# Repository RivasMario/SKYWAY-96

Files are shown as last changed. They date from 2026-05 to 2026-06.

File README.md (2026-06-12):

# SKYWAY 96 — Hotswap Keyboard PCB

A 96% mechanical keyboard PCB built around the RP2040, with Kailh hotswap sockets and underglow RGB. Designed for JLCPCB assembly and Melody96-compatible cases.

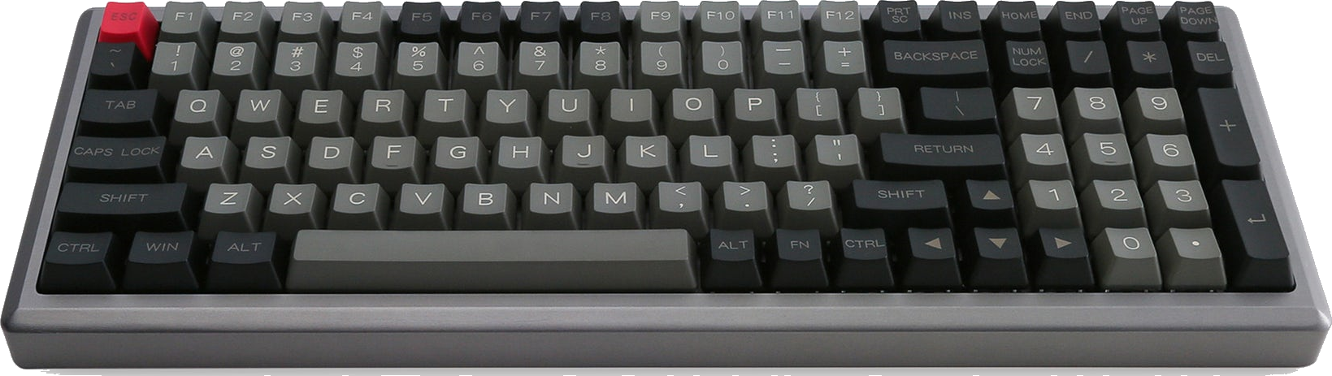
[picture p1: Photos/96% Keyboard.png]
Keyboard


## Contents

- [Specs](#specs)
- [Photos & Renders](#photos--renders)
- [Layout](#layout)
- [Repository Layout](#repository-layout)
- [Firmware: Setup & Flashing](#firmware-setup--flashing)
- [Troubleshooting](#troubleshooting)
- [Credits](#credits)

---

## Specs

| | |
|---|---|
| MCU | RP2040 (QFN-56) |
| Flash | W25Q128JVS (128 Mb, SOIC-8) |
| Layout | 96% — 99 keys |
| Switches | Kailh hotswap (MX compatible) |
| RGB | 18× WS2812B underglow |
| USB | USB-C (HRO TYPE-C-31-M-12) |
| Regulator | AMS1117-3.3 |
| ESD | PRTR5V0U2X |
| Firmware | QMK + VIA / Vial |
| Case | Melody96 / YMDK96 compatible (see [`Case/`](Case/)) |

---

## Photos & Renders

| Rendered Top | Rendered Back |
|---|---|
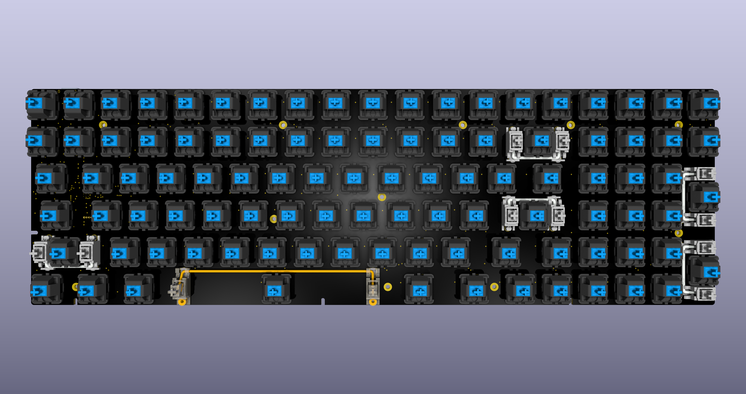
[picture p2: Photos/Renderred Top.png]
Rendered Top
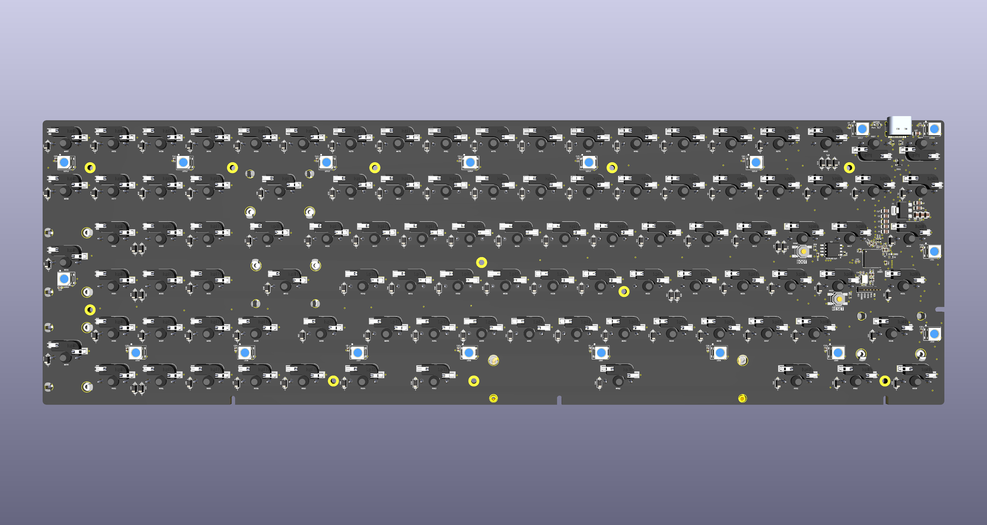
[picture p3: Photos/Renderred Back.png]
Rendered Back
|  |  |

| Board Top | Board Bottom |
|---|---|
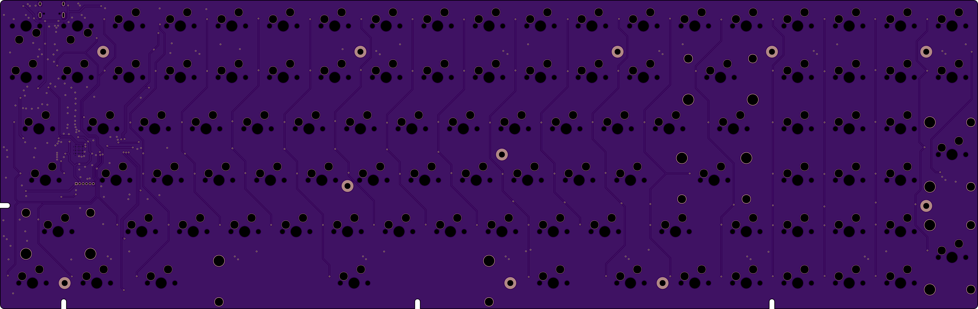
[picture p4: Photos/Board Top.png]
Board Top
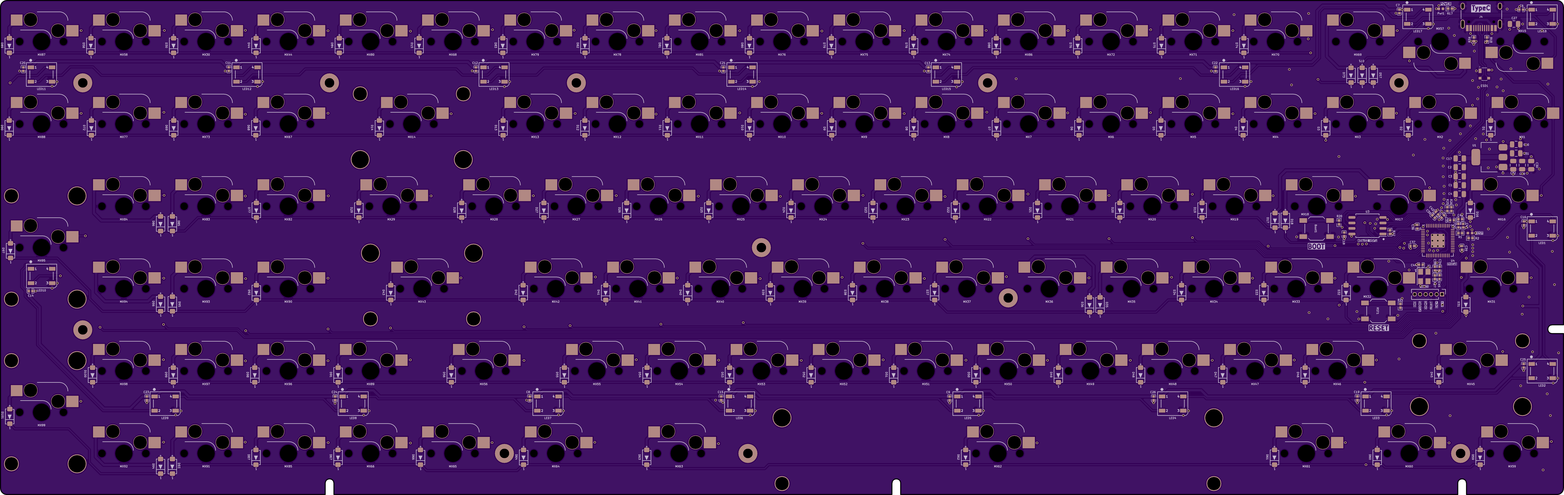
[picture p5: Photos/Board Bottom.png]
Board Bottom
|  |  |

All renders and 2D images (keycaps, stabilizers, layouts, alternate angles) live in [`Photos/`](Photos/).

### Switch Plate

Switch/stabilizer mounting plate (99 cutouts, 11× Ø4.0 screw holes, 361.95×114.30 mm).
DXF + details in [`Plate/`](Plate/).

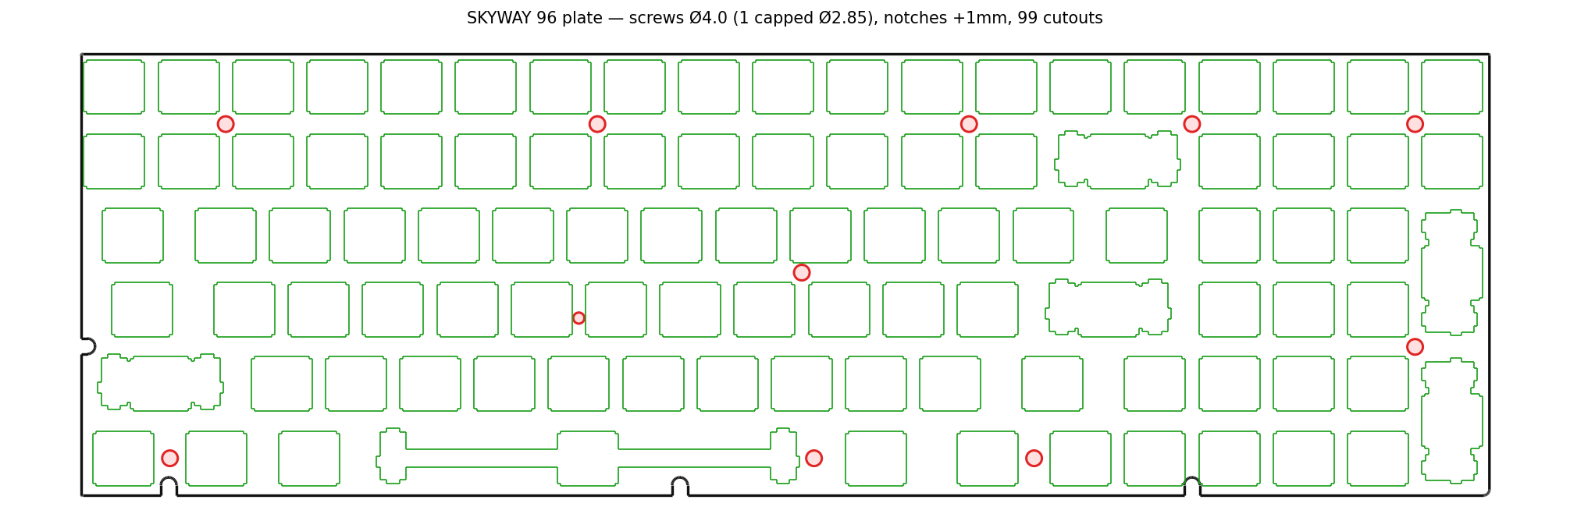
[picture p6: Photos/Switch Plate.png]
Switch plate


### 3D-Printable Cases

Two Melody96-compatible printed cases — pick either. Full part breakdowns in [`Case/`](Case/).

| Melody96 (HughMann) | RobotDoctor 96% |
|---|---|
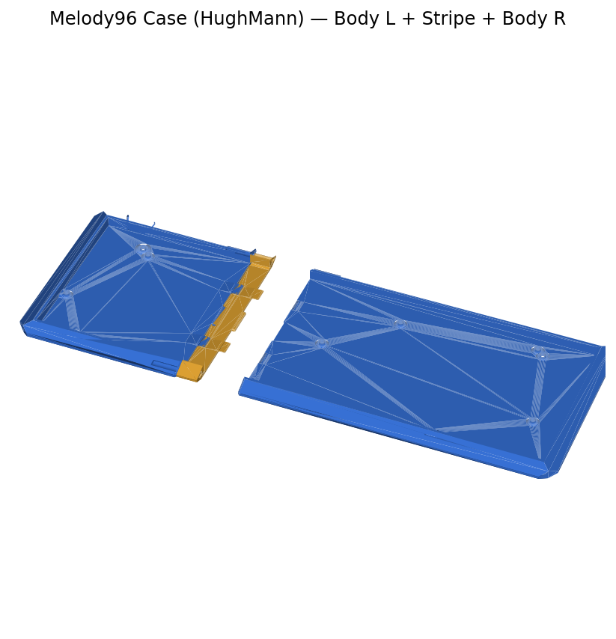
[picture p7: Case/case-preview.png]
Melody96 case
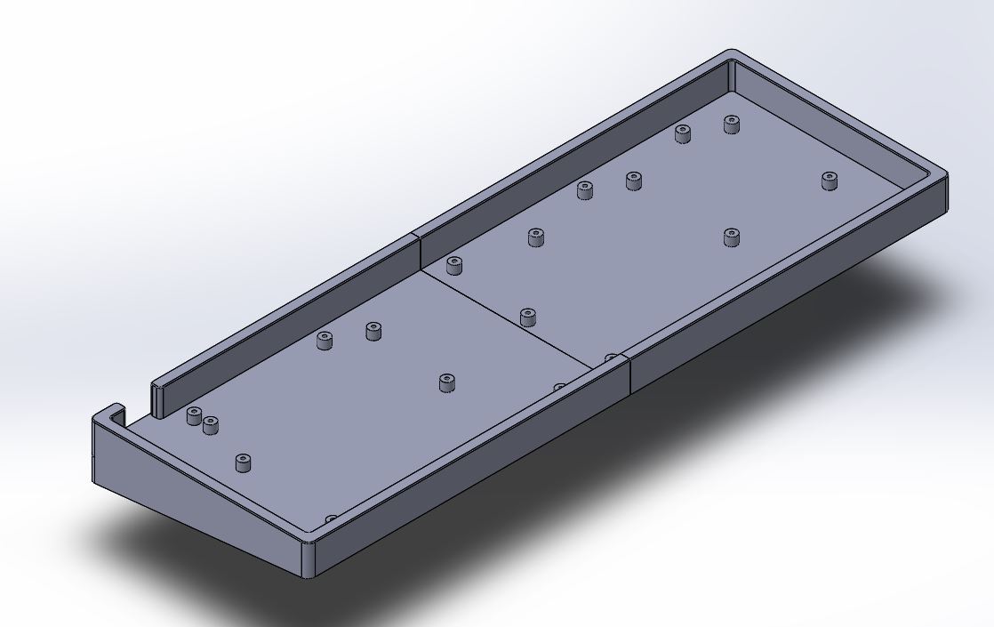
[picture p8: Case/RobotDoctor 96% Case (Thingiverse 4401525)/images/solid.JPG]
RobotDoctor case
|  |  |
| Multi-part: Body L/R + Stripe + Risers. [Details »](<Case/README.md>) · [Thingiverse #3883](https://www.thingiverse.com/thing:3883) | Tray-style, flat or angled. PCB-mount holes opened to Ø2.4 (M2). [Details »](<Case/RobotDoctor%2096%25%20Case%20%28Thingiverse%204401525%29/README.md>) · [Thingiverse #4401525](https://www.thingiverse.com/thing:4401525) |

---

## Layout

96% — 99 keys. Matrix is 6 rows × 19 columns (COL2ROW).

| 2D Layout | KLE |
|---|---|
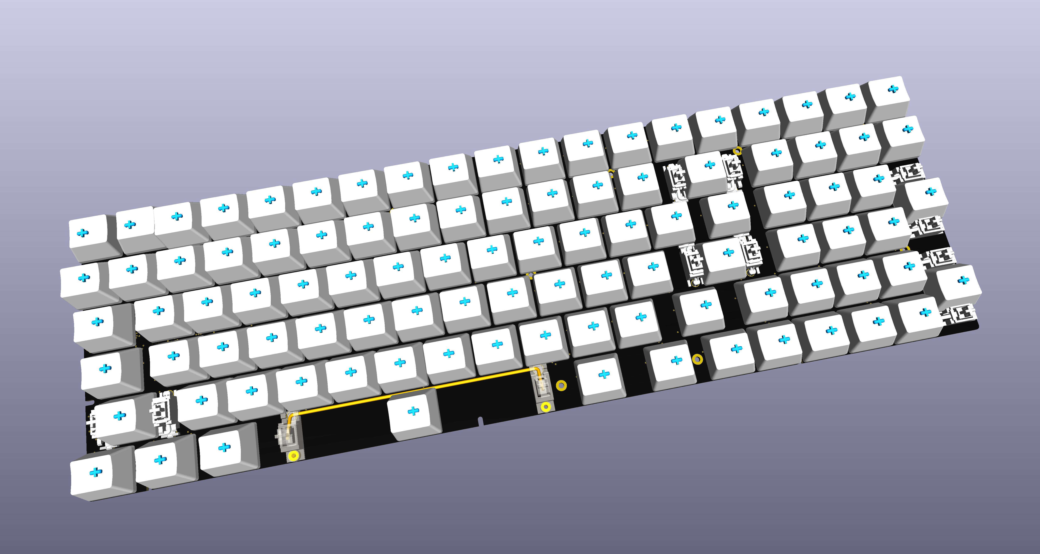
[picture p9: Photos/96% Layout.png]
96% Layout
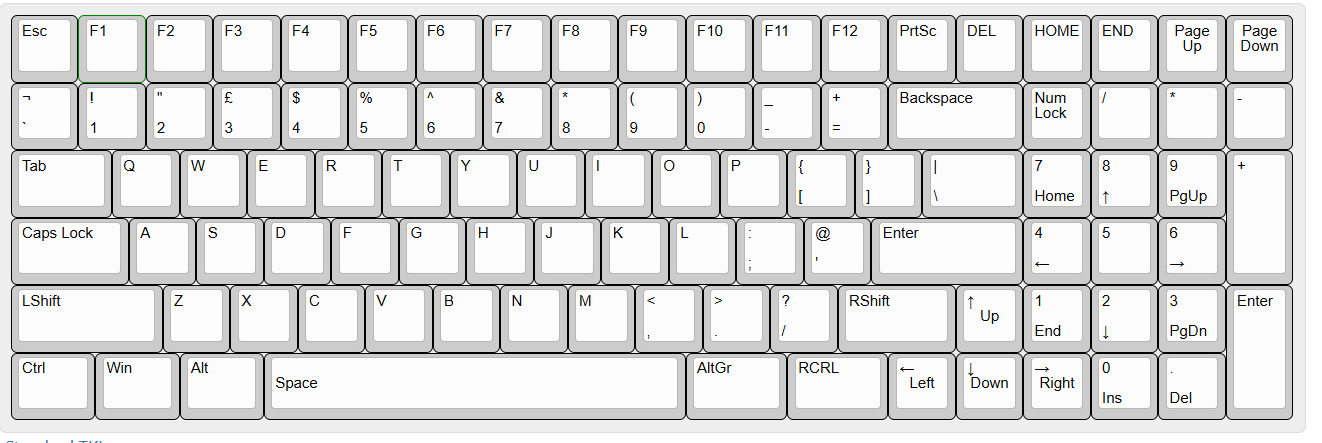
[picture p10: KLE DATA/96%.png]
Layout
|  |  |

Wiring, key labels, and VIA labelling diagrams are in [`KLE DATA/`](<KLE%20DATA/>).

---

## Repository Layout

| Folder | Contents |
|---|---|
| [`qmk_src/`](qmk_src/) | QMK firmware source + VIA keymap |
| [`Manufacturing & Assembly Files/`](<Manufacturing%20&%20Assembly%20Files/>) | BOM, CPL, Gerbers (for JLCPCB) |
| [`KiCAD Source Files/`](<KiCAD%20Source%20Files/>) | KiCad project + schematics |
| [`Schematic/`](Schematic/) | Schematic PDF |
| [`3D Step File/`](<3D%20Step%20File/>) | STEP / 3D model files |
| [`Photos/`](Photos/) | Renders and 2D images |
| [`KLE DATA/`](<KLE%20DATA/>) | Keyboard-Layout-Editor data + diagrams |
| [`VIA Json/`](<VIA%20Json/>) | VIA / Vial config + layout backups |
| [`Layout PDFs/`](<Layout%20PDFs/>) | Printable layout / keymap PDFs |
| [`Plate/`](Plate/) | Switch plate DXF (laser/waterjet) |
| [`Case/`](Case/) | 3D-printable cases (Melody96 + RobotDoctor) |

---

## Firmware: Setup & Flashing

### 1. Install the toolchain
You need the [QMK CLI](https://docs.qmk.fm/newbs_getting_started) and the `arm-none-eabi` toolchain. On Fedora:
```bash
sudo dnf install -y arm-none-eabi-gcc-cs-c++ arm-none-eabi-newlib arm-none-eabi-binutils
```

### 2. Link the source into QMK
```bash
ln -sf "$(pwd)/qmk_src" ~/qmk_firmware/keyboards/skyway96
```

### 3. Compile
```bash
qmk compile -kb skyway96 -km via
```
Produces `skyway96_via.uf2` in your `qmk_firmware` directory.

### 4. Flash
1. Enter bootloader: **hold BOOT → tap RESET → release BOOT**.
2. The board mounts as a USB drive named `RPI-RP2`.
3. Drag `skyway96_via.uf2` onto that drive, **or** run:
   ```bash
   qmk flash -kb skyway96 -km via
   ```

---

## Troubleshooting

### Linux USB detection (udev)
If VIA / Remap doesn't see the board on Linux, add a udev rule:
```bash
export USER_GID=`id -g`; sudo --preserve-env=USER_GID sh -c 'echo "KERNEL==\"hidraw*\", SUBSYSTEM==\"hidraw\", ATTRS{idVendor}==\"6969\", ATTRS{idProduct}==\"0096\", MODE=\"0660\", GROUP=\"$USER_GID\", TAG+=\"uaccess\", TAG+=\"udev-acl\"" > /etc/udev/rules.d/99-skyway96.rules && udevadm control --reload && udevadm trigger'
```

### Restore the "known good" layout
A verified layout backup (with RGB controls on Layer 1) lives at:
`VIA Json/skyway96_GOOD_BACKUP_2026-04-23.json`
Sideload it in VIA / Remap after flashing.

### GitHub push fails (password auth disabled)
Switch the remote to SSH:
```bash
git remote set-url origin git@github.com:RivasMario/SKYWAY-96.git
```
Make sure your SSH key (e.g. `~/.ssh/github`) is loaded in your SSH agent or set in `~/.ssh/config`.

---

## Credits

- **PCB** — Ahsan Mehmood Awan · `engrahsanmehmoodawan@gmail.com`
- **Case (Melody96)** — HughMann · [Thingiverse #3883](https://www.thingiverse.com/thing:3883)
- **Case (RobotDoctor 96%)** — RobotDoctor · [Thingiverse #4401525](https://www.thingiverse.com/thing:4401525) · CC-BY

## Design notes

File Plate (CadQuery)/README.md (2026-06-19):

# SKYWAY 96 — 3D-Printable Switch Plate (CadQuery)

A **3D-printable** version of the switch plate, generated from the same validated
geometry as the laser-cut [`../Plate/skyway96_plate.dxf`](../Plate/) (99 switch
cutouts incl. combo + stabilizer, 11 screw holes, 4 edge notches, PCB frame
361.95 × 113.30 mm). Pairs with the case in
[`../Case/SKYWAY Custom (CadQuery)`](../Case/SKYWAY%20Custom%20(CadQuery)).

## Why it isn't a flat 1.5 mm sheet

MX top-clips are made for a **1.5 mm** plate. A flat 1.5 mm × 360 mm FDM print
warps, flexes, and is fragile. So this is a **stepped** plate:

```
top  ──┐  1.5 mm   exact DXF profile (14 mm body + 1 mm clip wings)  → clips snap
body ──┘  1.5 mm   opened to ≥16 mm square                           → housing clears
total      3.0 mm  → stiff, low warp
```

The switch top (14 mm) seats in the top layer and the clip catches the step
shelf at z = 1.5 mm — exactly like a real 1.5 mm plate. The wider lower layer
just clears the switch's bottom housing and adds rigidity.

## Files

| File | What |
|---|---|
| `plate.py` | Builds the one-piece stepped plate → `output/skyway96_plate.stl` |
| `plate_split.py` | Left + Right halves for a ~220 mm bed → `output/skyway96_plate_{left,right}.stl` |
| `preflight.py` | Overhang / bed-fit / warp check |
| `tools/run_model.py` | Runs a script, validates watertight, renders a 6-view PNG |

Regenerate (uses the case folder's `.venv`):

```bash
PY="../Case/SKYWAY Custom (CadQuery)/.venv/Scripts/python.exe"
"$PY" plate.py            # one-piece
"$PY" plate_split.py      # L/R halves
"$PY" preflight.py
```

## Variants

| Print | Size (mm) | Bed |
|---|---|---|
| `skyway96_plate.stl` | 361 × 113 × 3 | 350 mm+ only |
| `skyway96_plate_left.stl` | 198 × 113 × 3 | any ≥ 220 |
| `skyway96_plate_right.stl` | 176 × 113 × 3 | any ≥ 220 |

### Split seam
At **x = 192 mm**, clear of the spacebar. A 96% layout has no full-height clear
column (stagger), so the seam **jogs** around the 3 cutouts it would cross —
every switch hole stays whole in one half, and the jog tongues key the halves
together in X and Y. Glue the seam faces; the PCB + screws lock the final stack.

## Screw holes (adaptive)

Each of the 11 holes is grown **as large as its neighbourhood allows** while
keeping a printable **1.0 mm** wall to the nearest cutout / hole / edge:

- 3 roomy holes (bottom row, near the edge) → **Ø5.0** (clears an M2 washer / a
  driver tip)
- 8 holes boxed in between switch cutouts → **~Ø2.4–2.5** (M2 shaft clearance)

The laser plate ran Ø4.0 everywhere on ~0.3 mm walls — fine for FR4, but those
walls won't print in FDM, so the crowded holes are deliberately smaller here.
Tune with `SCREW_WALL` / `SCREW_CAP_D` in `plate.py`.

## Print recipe

- Material: **PETG** (or PLA); 0.2 mm layers, 4 walls, 20 % infill
- **Print top-face DOWN** (flip in slicer) → the 14 mm clip openings print crisp
  on the bed and the step shelf prints fully supported. (Printed bottom-down also
  works; the ~1 mm step ledge is a trivial bridge.)
- **No supports.**
- **Brim** — 360 mm (one-piece) / ~190 mm (halves) flat parts are warp-prone.

## Assembly

1. Drop switches through the plate; clips snap at the 1.5 mm step.
2. Seat the switch pins into the PCB hotswap sockets (plate + PCB sandwich).
3. (split) glue the two halves at the jogged seam before populating across it.
4. Screw the PCB down into the case standoffs as normal.

## Source

Geometry from KiCad `MX1–MX99` switch centers via the laser plate DXF
([KB_PLATE_VALIDATOR](https://github.com/RivasMario/KB_PLATE_VALIDATOR)),
re-lofted to a stepped solid in CadQuery (OpenCASCADE).

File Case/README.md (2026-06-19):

# Case — SKYWAY 96

Case preview

Two 3D-printable case designs fit the SKYWAY 96 PCB. Both target the **Melody96 / YMDK96** 96% footprint the board is based on.

| Design | Folder | Construction | Tilt | Bed need |
|---|---|---|---|---|
| **Melody96 (HughMann)** | `Melody96 Case (HughMann)/` | 3-piece: L + Stripe + R (+ one-piece remix) | optional 5° riser | small (split) → large (1pc) |
| **96% (RobotDoctor)** | `96% Case (RobotDoctor)/` | 2-piece: L + R | built into model (angle vs flat) | small |
| **SKYWAY Custom (CadQuery)** | `SKYWAY Custom (CadQuery)/` | tray, 15× M2 posts; 1-piece **or** lap-split L/R; 6° feet | flat or 6° feet | 369 mm 1pc / 220 mm split |

The **SKYWAY Custom** tray is an original parametric design (CadQuery) fitted to
*this* PCB's exact outline + USB position — see its README to edit/regenerate.

See each folder's `README.md` for the full parts list.

---

## Design spec — what you need to make your own case

Both cases are built around the **same PCB**, so the hard constraints below are fixed. Everything else (wall style, seam, tilt) is a design choice — the two cases just make different choices.

### Fixed constraints (from the PCB / 96% standard)
| Spec | Value | Source |
|---|---|---|
| Layout footprint | Melody96 / YMDK96 96% | board lineage |
| Key pitch | 19.05 mm | MX standard |
| Switch cutout | 14.0 × 14.0 mm | MX plate |
| Plate thickness | 1.5 mm | MX clip seat |
| Mount holes present | M2 (1.75 mm) + M3 (3.0 mm) | `NPTH.drl` |
| PCB outline ref | `3D Step File/PCB 3D.step` | exact edge + holes |

### How the two cases solve it
| Aspect | Melody96 (HughMann) | 96% (RobotDoctor) |
|---|---|---|
| Pieces | 3 (L + Stripe + R) | 2 (L + R) |
| Seam | center stripe joins halves | direct center seam |
| Alignment | printed dowels | model-mated edge |
| Tilt | separate 5° riser parts | baked in: **angle** or **flat** body |
| Wall options | standard **or** 2 mm | single wall (per variant) |
| Assembled W × D × H | 387.6 × 140.3 × 21.7 mm | ≈376 × 128.8 × 31.5 (angle) / 18.0 (flat) |
| Half max footprint | 221.9 × 140.3 mm (Body R) | 188.0 × 128.8 mm |
| PCB hold | standoffs + dowels + feet | integrated bosses |
| Extras included | risers, feet, dowels, standoffs, remixes | none — body only |

### Compare / contrast — takeaways
- **Modularity:** Melody96 is a kit (swap stripe, risers, wall thickness, remixes). RobotDoctor is monolithic — fewer choices, fewer parts to align.
- **Tilt strategy:** Melody96 = add-on riser (mix and match). RobotDoctor = pick angle vs flat at print time (no extra parts, but no in-between).
- **Print effort:** RobotDoctor halves (max 188 mm) print on any bed with no stripe/dowel steps. Melody96 split also fits small beds but has more pieces; its one-piece remix needs a ~388 mm bed.
- **Assembly:** Melody96 needs dowels + standoffs + feet. RobotDoctor mates halves directly.
- **Hardware:** Melody96 ships printable hardware (feet/dowels/standoffs); RobotDoctor expects you to mount the PCB to integrated bosses (see its `Images/pcb_marked_1.jpg`).

### To design a fresh case
1. Pull exact outline + hole positions from `3D Step File/PCB 3D.step`.
2. Pull key positions from `skyway96.layout.json` (or `KLE DATA/`).
3. Use the fixed constraints table above for plate cutouts (19.05 pitch, 14×14, 1.5 mm).
4. Choose construction (tray / sandwich / split like these two), tilt, wall thickness.

Want a parametric OpenSCAD case generated from these? Pick tray vs sandwich and a tilt angle.

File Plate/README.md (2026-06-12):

# Switch Plate

Switch/stabilizer mounting plate for the SKYWAY 96 PCB.

Switch plate

| | |
|---|---|
| Size | 361.95 × 114.30 mm |
| Switch cutouts | 99 (Cherry MX, 14 mm) incl. combo cutouts (space, enter, backspace, numpad enter/plus) |
| Screw holes | 11 × **Ø4.0** (M2 + washer); 1 capped to Ø2.85 (PCB-constrained), aligned to PCB mounting holes |
| Edge notches | 4 (bottom + left + right), **grown +1 mm** for clearance |
| Format | `skyway96_plate.dxf` — layered (outline / switch / stab / screw) |

Cut from 1.5 mm FR4, brass, aluminium, or POM (laser / waterjet). The DXF is
SendCutSend-ready (no zero-length segments).

**Changes from PCB-exact:** screw holes opened Ø2.4→**Ø4.0** and notches grown
+1 mm for generous install wiggle; the bottom row left of the arrows is **2 wide
keys (1.5u each — RCtrl + Fn)** instead of three 1u, matching the PCB's two
switches there. Holes are sized **per-hole**: as big as Ø4.0 while keeping a
≥0.3 mm wall to the nearest switch cutout — one PCB-constrained hole is therefore
capped at Ø2.85. **Holes >3.8 mm need a washer** (M2 head is ~3.8 mm) — that's 10 of 11 here. Regenerate via `scripts/postprocess_plate.py --screw-dia ... --min-wall ...`.

## Source

Generated from the KLE layout + `KiCAD Source Files/*.kicad_pcb` by
[**KB_PLATE_VALIDATOR**](https://github.com/RivasMario/KB_PLATE_VALIDATOR),
which auto-registers the plate to the PCB and validates that every M2 screw
clears all switch/stab cutouts. Regenerate:

```bash
python scripts/build_plate.py \
  --kle skyway96_kle.json \
  --pcb "../skyway-96/KiCAD Source Files/rivasmario 96% Hotswap Rp2040.kicad_pcb" \
  --out output/skyway96_plate.dxf --pad 0 --snap-screws
```

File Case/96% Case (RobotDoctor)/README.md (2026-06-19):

# Case — 96% (RobotDoctor)

Second 3D-printable case option for the SKYWAY 96 PCB.

Design by **RobotDoctor** — [Thingiverse thing #4401525](https://www.thingiverse.com/thing:4401525). Files mirrored here for convenience; CC Attribution license (see `LICENSE.txt`).

## Print Layout

Prints in two halves (**left** + **right**), no center stripe. Choose **one** tilt variant:

```
[ left half ] [ right half ]
   angle  (5° typing tilt)
   flat   (0° low profile)
```

## Parts

### `Main Body/`
| File | Notes |
|---|---|
| `96plate_angle_left.STL` / `96plate_angle_right.STL` | Tilted variant — built-in typing angle |
| `96plate_flat_left.STL` / `96plate_flat_right.STL` | Flat variant — low profile |

> Print **either** the angle pair **or** the flat pair — not both.

## Dimensions (STL bounding box, mm)

| File | W × D × H |
|---|---|
| `96plate_angle_left` / `_right` | 188.0 × 31.5 × 128.8 |
| `96plate_flat_left` / `_right` | 188.0 × 18.0 × 128.8 |

Halves are modeled on their side (Z = board depth). Two halves seam at center → assembled width ≈ 376 mm. Fits the Melody96 / YMDK96 96% footprint shared by the SKYWAY 96 PCB.

## Print Tips

- **Material:** PLA or PETG.
- **Bed size:** each half ≈ 188 × 129 mm — fits most beds; no large-bed one-piece needed.
- **Orientation:** print as oriented (long axis up) for clean side walls, or lay flat if your slicer adds supports for the key cutouts.
- See `Images/pcb_marked_1.jpg` for PCB mounting reference.

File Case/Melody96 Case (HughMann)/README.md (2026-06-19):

# Case — Melody96 (HughMann, 3D Printable)

3D-printable case for the SKYWAY 96 PCB. The board shares the **Melody96 / YMDK96** footprint, so any Melody96-compatible case fits.

Design by **HughMann** — [Thingiverse thing #3883](https://www.thingiverse.com/thing:3883). Files mirrored here for convenience; original license terms apply.

## Print Layout

Prints in two halves (**Body L** + **Body R**) joined by a center **Stripe** accent piece. Add **Risers** for tilt and **Hardware** for assembly.

```
[ Body L ] [ Stripe ] [ Body R ]
              + Risers (tilt)
              + Feet / Dowels / Standoffs
```

## Parts

### `Main Body/`
| File | Notes |
|---|---|
| `Body L.stl` / `Body R.stl` | Left + right case halves (standard wall) |
| `Body L 2mm.stl` / `Body R 2mm.stl` | Thicker 2 mm wall variant — stiffer, more filament |
| `Stripe.stl` | Center accent strip that joins the two halves |
| `3 Part Stripe.stl` | Stripe split into 3 pieces — for smaller print beds |

> Print **either** the standard halves **or** the 2 mm halves — not both.

### `Risers/`
Add a 5° typing tilt.
| File | Notes |
|---|---|
| `5 Degree Riser Single Piece.stl` | One-piece riser (needs a large bed) |
| `5 Degree Riser L.stl` / `5 Degree Riser R.stl` | Split riser for smaller beds |

### `Hardware/`
| File | Notes |
|---|---|
| `Feet.stl` | Bottom feet |
| `Dowel.stl` | Alignment pins joining the case halves |
| `Extra standoff.stl` | Spare PCB mounting standoff |

### `Remixes/`
Community variants — alternate styling, same fit.
| File | Notes |
|---|---|
| `Granular Theory (Stoic Reluctance) Body L M2.stl` | Remix left half (M2 hardware) |
| `Granular Theory (Stoic Reluctance) Body R M2.stl` | Remix right half (M2 hardware) |
| `Granular Theory (Stoic Reluctance) Stripe M2.stl` | Remix center stripe |
| `Hope Lost (Sincerity or Rejection) One-Piece File.stl` | One-piece remix body |

## Dimensions (STL bounding box, mm)

| Part | W × D × H |
|---|---|
| Full assembled | 387.6 × 140.3 × 21.7 |
| Body L | 126.2 × 140.3 × 21.7 |
| Body R | 221.9 × 140.3 × 21.7 |
| Stripe | 20.5 × 138.3 × 21.7 |
| One-piece remix | 387.6 × 140.3 × 21.7 |
| 5° riser (1pc) | 342.5 × 15.0 × 10.2 |

## Print Tips

- **Material:** PLA or PETG.
- **Orientation:** print bodies flat (open side up) for clean key cutouts.
- **Bed size:** if a single-piece part won't fit, use the split equivalent (`3 Part Stripe`, split risers).
- **Mounting:** dowels align the halves; standoffs hold the PCB.

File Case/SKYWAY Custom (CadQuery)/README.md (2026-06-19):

# Case — SKYWAY Custom Tray (parametric, CadQuery)

Original tray case for the SKYWAY 96 PCB, built in **CadQuery** (Python/OpenCASCADE).
Every dimension is driven from *this repo's* gerbers + KiCad PCB — not guessed — so
it fits the real board. Fully parametric: edit the constants in `skyway_case.py`
and re-run.

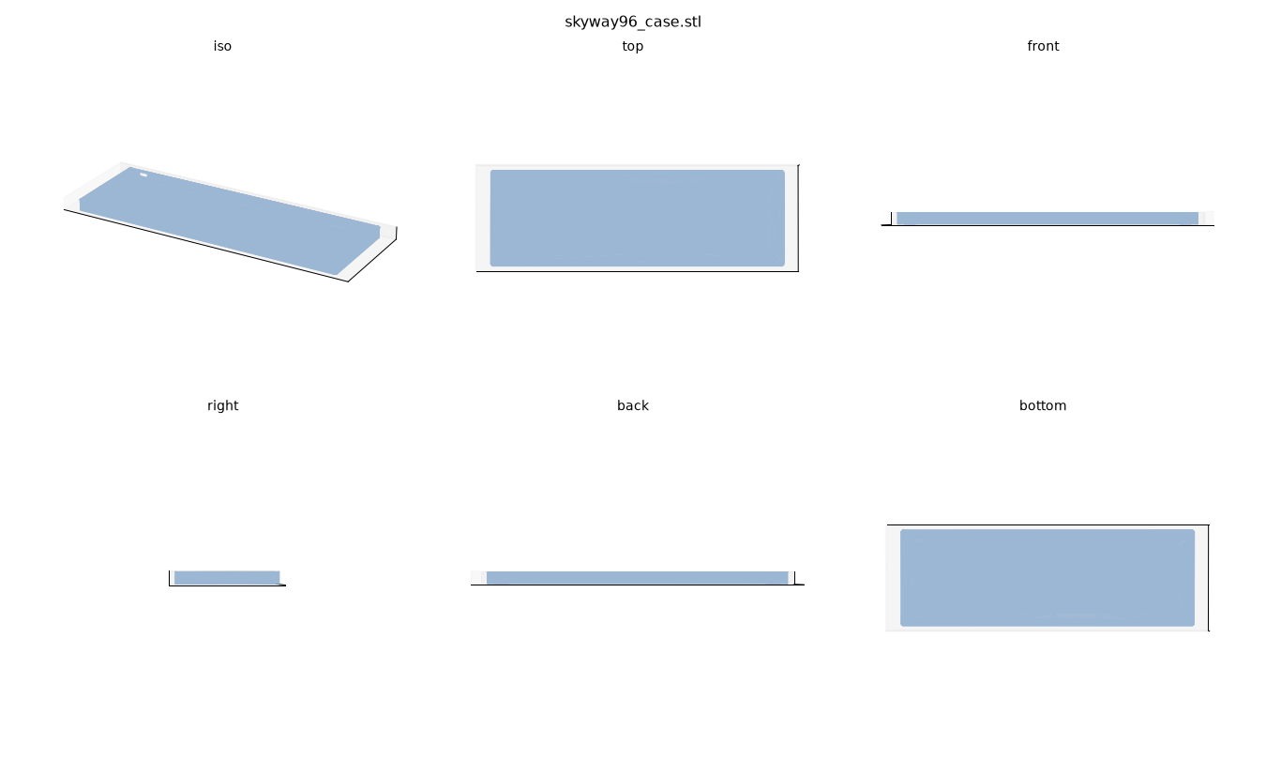
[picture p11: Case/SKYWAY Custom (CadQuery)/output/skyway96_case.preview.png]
preview


## What it is

A low-profile **screw-mounted tray**. The PCB drops in from the top and is held
three ways — anti-wobble by design:

1. **Continuous perimeter support ledge** (2.2 mm) under the PCB edge — all-around bearing.
2. **15 M2 standoff posts** — 11 at the PCB's internal mount holes + 4 at the
   edge screw-notches. The PCB screws **down** into them → clamped, not resting → no
   push-down bounce.
3. **Thin clamp lip** (0.8 mm) over the edge — backup hold-down between screws.

Ledge tops and post tops are coplanar at Z = 6.5 mm, so the PCB beds flat and
can't rock. All three features live in the 2.5 mm gap between the PCB edge and the
first switch housing, so nothing fouls switches or keycaps.

Fastening: **M2 heat-set brass inserts** (`screw_mode = "insert"`; 6.5 mm posts,
3.2 mm bore). Set `screw_mode = "selftap"` for screw-into-plastic (5 mm posts,
1.65 mm pilot) if you'd rather skip the inserts.

## Orientation (matches the physical board)

- **USB-C** exits the **far (+Y) wall, right end** — the diagonal corner
  (`USB_FAR_CORNER = True`).
- The **4 edge-notch posts** sit on the **opposite long edge** from the USB hole
  (`FLIP_X = True` mirrors the posts left↔right; the USB stays put).

The PCB only drops in one way (USB aligns to its cutout), so the assembly is
self-orienting — it can't go in backwards.

## Fit data (measured, not guessed)

| Source | Value |
|---|---|
| `Gerber File/...Edge_Cuts.gm1` | PCB outline **361.95 × 114.30 mm** |
| — | = exactly 19 × 6 keys @ 19.05 mm → the PCB *is* the switch grid, **no border** |
| `...kicad_pcb` (J4) | USB-C connector position |
| `...kicad_pcb` MountingHole + Edge.Cuts arcs | 11 M2 mount holes + 4 edge notches |
| 96% / MX standard | 19.05 pitch, 14 × 14 cutout, 2.5 mm edge-to-housing gap |

## Dimensions

| | mm |
|---|---|
| Outer (W × D × H) | **368.8 × 121.1 × 15.1** |
| Cavity (PCB pocket) | 362.8 × 115.1 |
| Wall / floor | 3.0 / 2.5 |
| PCB sits at Z | 6.5 (4.0 mm standoff above floor) |
| Material volume | ≈ 155 cm³ |

## Variants

| Script | Output | Bed |
|---|---|---|
| `model.py` | `skyway96_case.stl` | one-piece — needs **350 mm+** |
| `split.py` | `skyway96_left.stl` (~200 mm) + `skyway96_right.stl` (~175 mm) | **220 mm+** |
| `feet.py`  | `skyway96_foot.stl` — **print ×2** | any |

### Split — drop-in dovetails
Seam is offset to a **key-column gap** (centered-X +9.5 mm) so it misses every
standoff post. The joint is a row of **4 drop-in dovetails** on a raised **seam
rib**: each tenon flares in Y, so once seated the halves can't pull apart in X.
Tenons extrude vertically (constant in Z) → they **print support-free**, and you
**seat the right half straight down** onto the left. (A true *sliding* dovetail
can't work on a left/right split — the case bodies collide before the joint
engages.) The seam rib doubles as an **anti-sag gusset** and stays below the
hotswap sockets so it never touches the PCB.

The dovetails lock and align the **bottom**. The two long **walls just butt** —
**glue the seam faces** (superglue/epoxy) to lock the walls; the dovetails hold
the alignment while it sets. Glue is permanent and stronger than the plastic; for
a removable joint, model a bottom splice plate instead.

### Tilt — 6° dovetail-rail feet
One symmetric foot design (**print ×2**, one per channel). Each has a **male
dovetail rail** on its flat top that **slides along Y into a channel cut in the
case bottom** (added automatically when `FEET_DOVETAIL = True`). The dovetail
captures the foot — it can't drop off — and the wedge tilts the board **USB-edge
up** (front 3 mm → back 15.7 mm), the standard typing angle. Slide a foot into
each channel from the end; friction holds, add glue to make it permanent. Change
`FOOT["tilt_deg"]` in `skyway_case.py` for a different angle.

## Print recipe

- **Material:** PLA or PETG (PETG tougher at this span; print it in an enclosure).
- **Orientation:** body/halves open-side-up, floor flat on the bed. Feet on their
  **6° sloped face** (it's flat → fully supported).
- **Settings:** 0.2 mm layer, 3–4 walls, 15 % gyroid infill.
- **Supports:** none — every overhang is a short bridge (USB top, lip, dovetail
  flares ≤ ~13 mm). Verified by `preflight.py`.
- **Adhesion:** **brim** on the long flat parts — they're warp-prone.
- **First-layer compensation** (~0.15 mm) helps the dovetail fit (elephant's foot
  otherwise fattens the tenons).

## Bill of materials

- 15 × **M2 heat-set inserts** + 15 × M2 screws (PCB → posts)
- 2 × printed tilt feet (optional)
- **Glue / epoxy** for the split seam (if printing the split version)

## Assembly

1. Heat-set the **15 M2 inserts** into the posts.
2. *(split only)* seat the **right half down onto the left** so the dovetails
   drop in, then **glue the seam faces**.
3. Drop the **PCB** into the tray (rests on the ledge + post tops) and drive the
   **M2 screws** down through the PCB holes/notches into the posts.
4. *(optional)* slide a **tilt foot** into each bottom channel.

## Setup / regenerate

```bash
python -m venv .venv
.venv/Scripts/python.exe -m pip install cadquery trimesh numpy matplotlib
.venv/Scripts/python.exe tools/run_model.py model.py --preview   # build + 6-view PNG
.venv/Scripts/python.exe split.py        # split halves
.venv/Scripts/python.exe feet.py         # tilt foot
.venv/Scripts/python.exe preflight.py    # printability check
```

(`.venv` is gitignored — 761 MB, recreate with the commands above.)

## Parameters (in `skyway_case.py` unless noted)

| Param | Effect |
|---|---|
| `wall`, `floor`, `above_pcb` | thickness / stiffness / wall height above PCB |
| `lip_w`, `ledge_w` | clamp / support overhang (shrink if it clips switches) |
| `screw_mode` | `"insert"` (heat-set) or `"selftap"` |
| `FLIP_X` | mirror posts left↔right (USB fixed) |
| `USB_FAR_CORNER` | USB-C on the far wall, right end (diagonal corner) |
| `FEET_DOVETAIL` | cut the foot channels in the bottom |
| `FOOT["tilt_deg"]` | tilt angle of the feet |
| `BEZEL` / `STRIPE` | optional exterior flair (off by default) |
| seam / dovetail params (`split.py`) | seam X, dovetail count/size, clearance |

## Files

```
skyway_case.py   shared case builder (single source of truth)
model.py         one-piece body
split.py         L/R dovetail split
feet.py          6° tilt foot
preflight.py     printability / overhang check
tools/run_model.py   build runner + matplotlib 6-view preview
output/          generated STLs + preview PNGs
```

Built with the phased CAD workflow (base shell → features → fillets → flair),
each stage previewed and validated watertight before moving on.

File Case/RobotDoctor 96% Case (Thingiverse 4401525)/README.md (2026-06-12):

# RobotDoctor 96% Case (Thingiverse 4401525)

3D-printable case for a **96% mechanical keyboard** (Melody96 / YMDK96-class PCB),
an alternate to the [Melody96 (HughMann) case](../Melody96%20Case%20%28HughMann%29/).

Source design: **"Mechanical Keyboard Case for 96% Keyboard"** by
[RobotDoctor on Thingiverse](https://www.thingiverse.com/thing:4401525)
(thing **4401525**). Licensed **Creative Commons — Attribution (CC-BY)**.
See [`LICENSE.txt`](LICENSE.txt). This repo archives the original files,
adds build notes, and tracks local modifications.

## Render

Assembled case render

The case is a tray-style bottom: a perimeter wall with **standoffs** the PCB
screws down onto. Because a 96% board is long, the tray is **split into left +
right halves** so each fits a normal print bed; the seam sits mid-case.

## What's in here

| File | Half | Profile |
|---|---|---|
| [`plates/96plate_flat_left.STL`](plates/96plate_flat_left.STL) | left  | flat (0°) |
| [`plates/96plate_flat_right.STL`](plates/96plate_flat_right.STL) | right | flat (0°) |
| [`plates/96plate_angle_left.STL`](plates/96plate_angle_left.STL) | left  | angled (typing tilt) |
| [`plates/96plate_angle_right.STL`](plates/96plate_angle_right.STL)| right | angled (typing tilt) |

Pick **one profile** (flat *or* angle) and print **both halves** of it.

3D renders of the four modified plates (Ø2.4 bores):

| Flat | Angle |
|---|---|
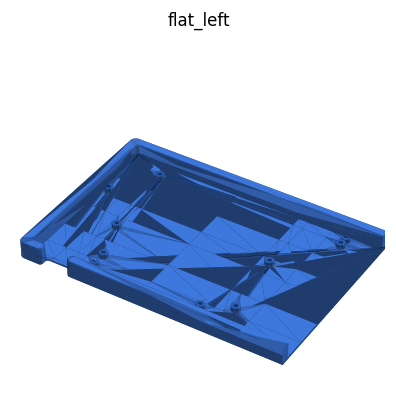
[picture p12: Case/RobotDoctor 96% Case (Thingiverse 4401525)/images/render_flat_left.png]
flat left
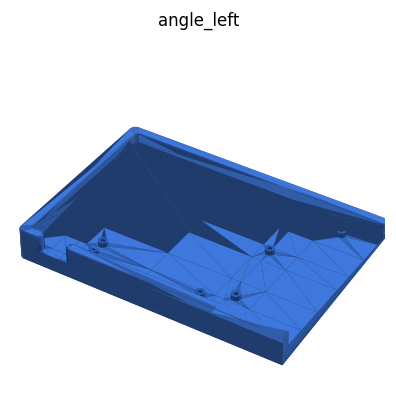
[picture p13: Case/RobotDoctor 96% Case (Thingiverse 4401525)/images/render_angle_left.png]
angle left
|  |  |
| `flat_left`  | `angle_left`  |
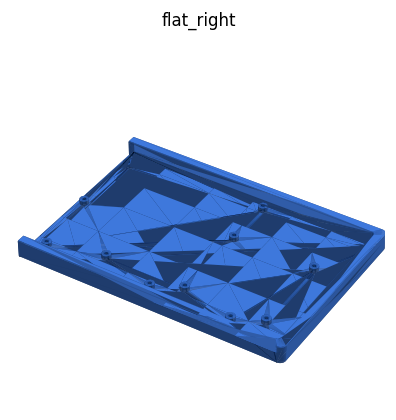
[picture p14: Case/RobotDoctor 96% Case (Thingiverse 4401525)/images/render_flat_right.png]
flat right
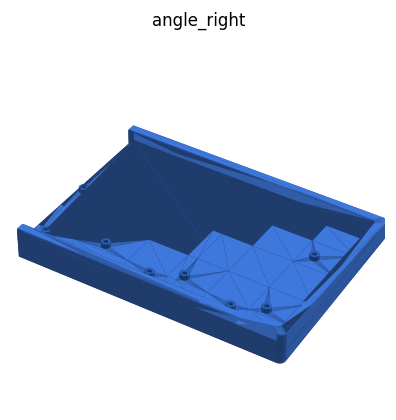
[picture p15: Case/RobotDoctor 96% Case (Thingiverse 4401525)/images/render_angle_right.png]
angle right
|  |  |
| `flat_right` | `angle_right` |

PCB used, screw holes marked in red (tape measure for scale):

PCB with mounting holes marked

## Print

1. Choose profile — **flat** (board sits flat) or **angle** (built-in typing tilt).
2. Slice `*_left` and `*_right` of that profile.
   - Material: PLA or PETG.
   - Layer height: 0.2 mm.
   - Walls: ≥ 3 perimeters (the standoffs take screw load).
   - Infill: ≥ 20% (bump standoffs/walls denser if your slicer supports modifiers).
   - Supports: only if your orientation needs them; the tray prints best
     **open-side up** (flat on the bed) — no supports for the flat profile.
3. Print both halves.

## Assemble

1. Dry-fit the two printed halves together at the center seam.
2. Drop the **PCB** into the tray, aligning its mounting holes over the standoffs
   (see the marked photo above — ~14 points).
3. Screw the PCB down into the standoffs (M2 screws).
4. Seat switches/stabs, add plate/keycaps, close it up.

## Screw-hole fix (applied)

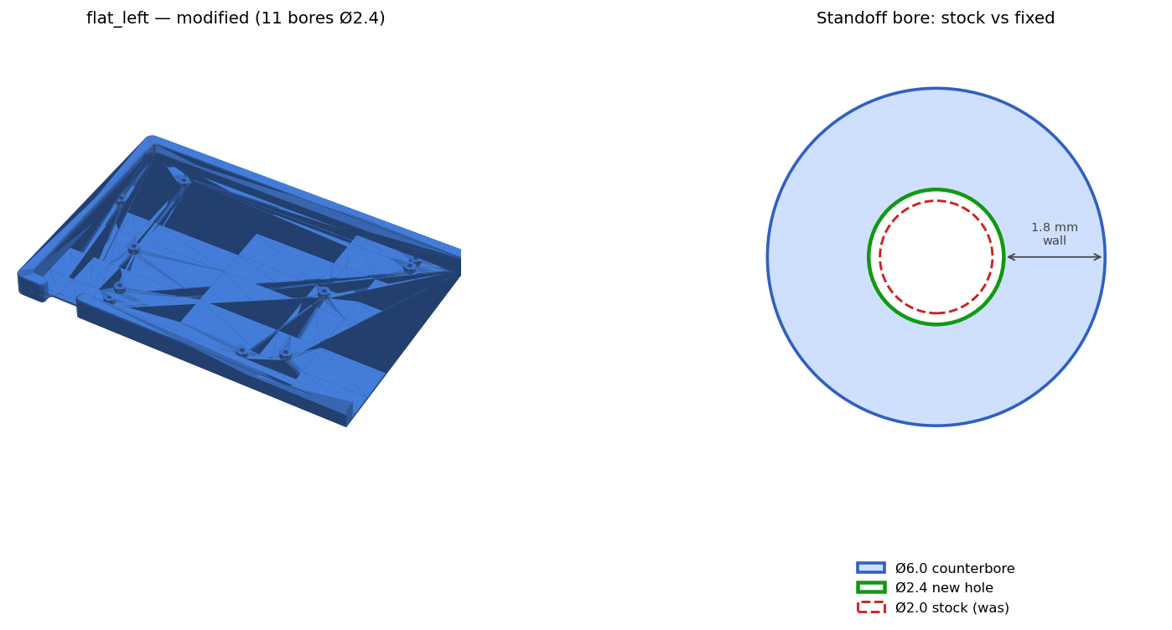
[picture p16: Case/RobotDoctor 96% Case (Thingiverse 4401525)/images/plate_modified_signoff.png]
Modified plate — 3D view + bore detail


*Left: modified `flat_left` (11 bores opened to Ø2.4). Right: standoff bore —
red dashed = Ø2.0 stock, green = Ø2.4 new, both inside the Ø6.0 counterbore;
~1.8 mm wall retained.*

The **stock** standoff holes are **Ø2.0 mm** — zero clearance for an M2 screw
(M2 major dia *is* 2.0 mm), so the screw won't pass and the holes had to be
drilled out by hand.

The STLs in [`plates/`](plates/) are **modified**: each of the 11 PCB-mount
bores per half is opened to **Ø2.4 mm** (M2 normal clearance) — screw passes
freely, head still seats in the Ø6 mm counterbore, ~1.8 mm wall retained. The
Ø6 counterbores and case corner/seam posts are untouched. Print these as-is —
no drilling needed.

- Unmodified Ø2.0 originals: [`original/plates/`](original/plates/).
- Re-cut: 4 plates × 11 bores, boolean difference (trimesh + manifold3d),
  result watertight. To change the diameter, copy back the originals and
  re-run with a different target.

## Credits

- Original design © [RobotDoctor](https://www.thingiverse.com/thing:4401525), CC-BY.
- Modifications and build notes: RivasMario.

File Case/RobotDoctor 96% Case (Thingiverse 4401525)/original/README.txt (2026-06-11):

Mechanical Keyboard Case for 96% Keyboard by RobotDoctor on Thingiverse: https://www.thingiverse.com/thing:4401525

Summary:
Mechanical Keyboard case made for a friend, sorry it took so long.

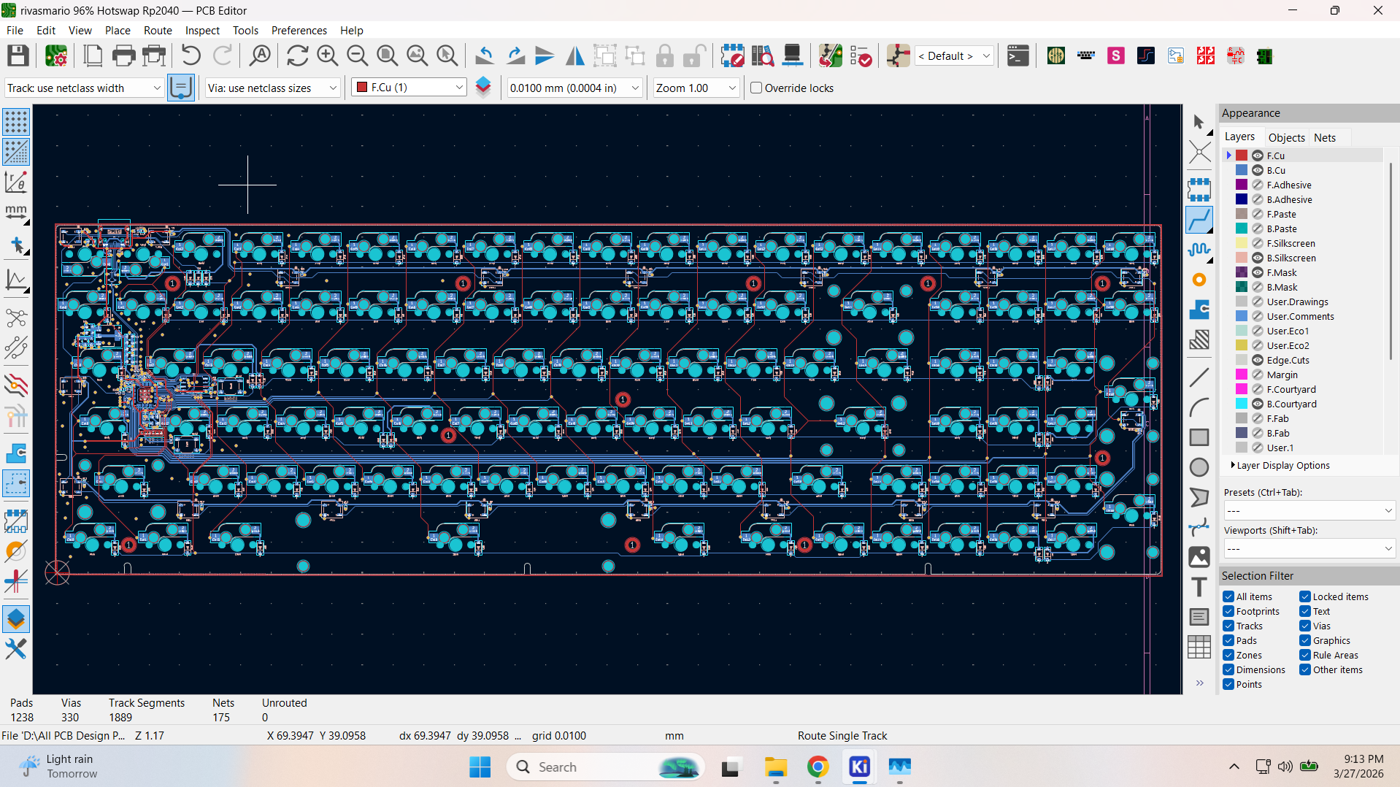
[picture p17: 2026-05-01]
Photos/PCB Layout.png

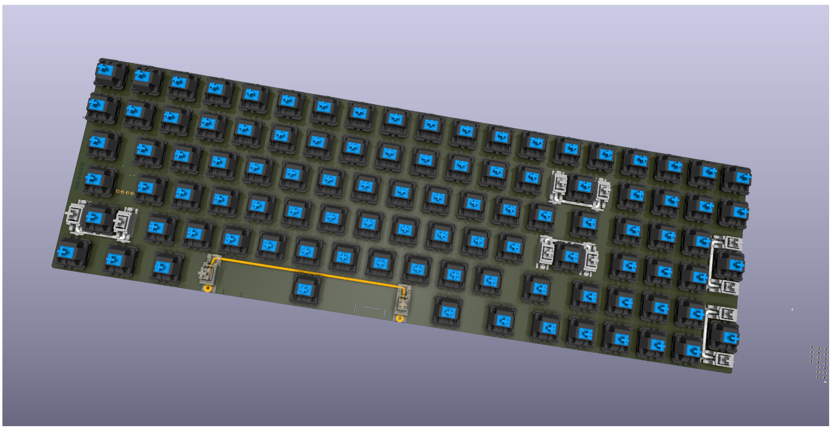
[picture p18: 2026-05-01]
Photos/3D.png

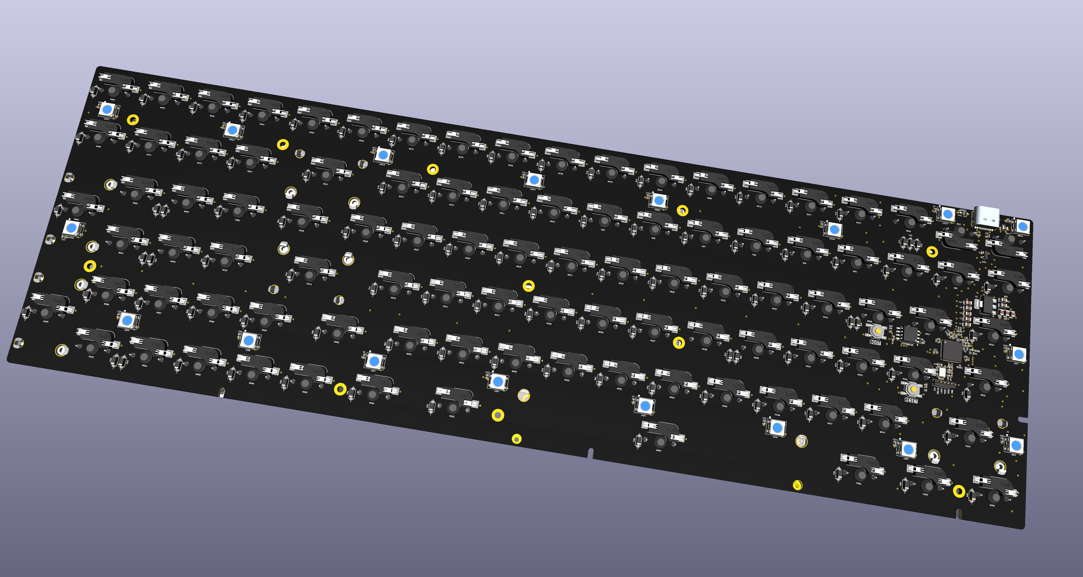
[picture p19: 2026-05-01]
Photos/back 3d.png

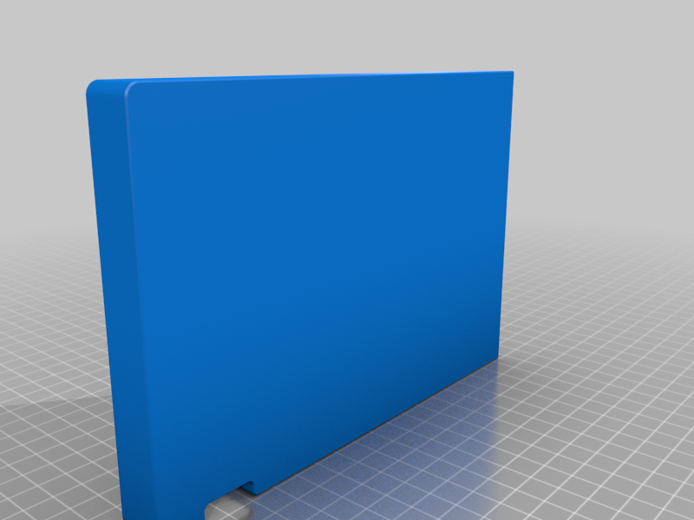
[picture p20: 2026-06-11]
Case/96% Case (RobotDoctor)/Images/96plate_flat_left.png

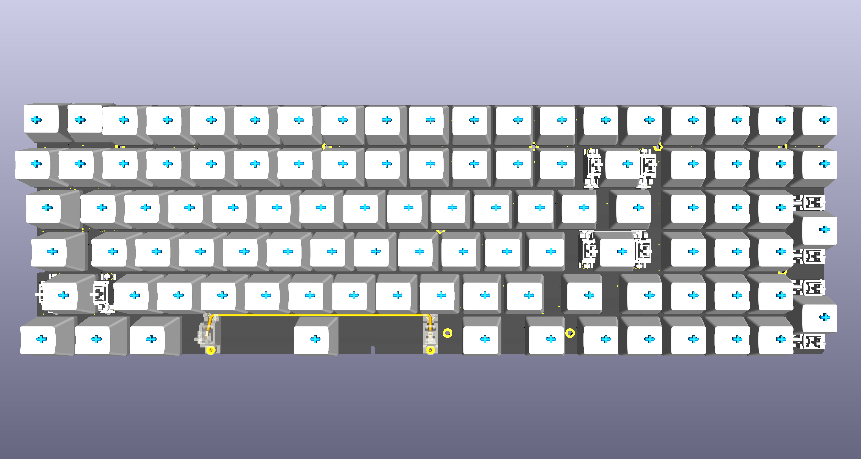
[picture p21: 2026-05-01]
Photos/Keycaps.png

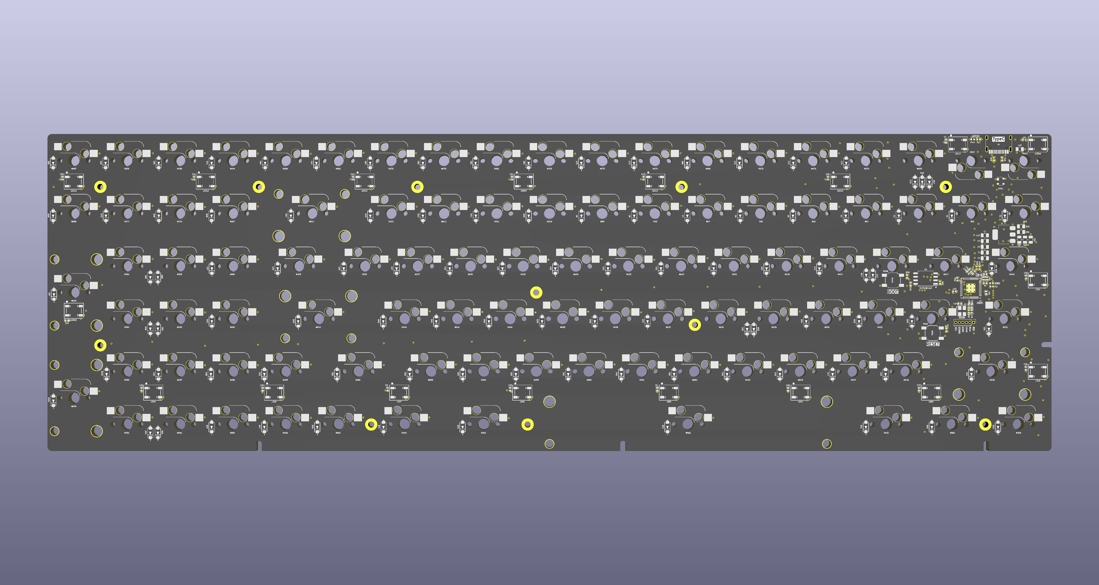
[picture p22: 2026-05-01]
Photos/Back 2D.png

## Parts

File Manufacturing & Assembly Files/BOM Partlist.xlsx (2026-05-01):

Reference | Value | Footprint | Qty | JLCPCB Part #
U1 | AMS1117-3.3 | Package_TO_SOT_SMD:SOT-223-3_TabPin2 | 1 | C6186
Test1 | LED | LED_SMD:LED_0402_1005Metric | 1 | C131223
Pwr1 | LED | LED_SMD:LED_0402_1005Metric | 1 | C131223
J4 | USB_C_Receptacle_USB2.0 | Ahsan Libs:USB_C_Receptacle_HRO_TYPE-C-31-M-12 | 1 | C165948
MX1,MX2,MX3,MX4,MX5,MX6,MX7,MX8,MX9,MX10,MX11,MX12,MX13,MX14,MX15,MX16,MX17,MX18,MX19,MX20,MX21,MX22,MX23,MX24,MX25,MX26,MX27,MX28,MX29,MX30,MX31,MX32,MX33,MX34,MX35,MX36,MX37,MX38,MX39,MX40,MX41,MX42,MX43,MX44,MX45,MX46,MX47,MX48,MX49,MX50,MX51,MX52,MX53,MX54,MX55,MX56,MX57,MX58,MX59,MX60,MX61,MX62,MX63,MX64,MX65,MX66,MX67,MX68,MX69,MX70,MX71,MX72,MX73,MX74,MX75,MX76,MX77,MX78,MX79,MX80,MX81,MX82,MX83,MX84,MX85,MX86,MX87,MX88,MX89,MX90,MX91,MX92,MX93,MX94,MX95,MX96,MX97,MX98,MX99 | MX-NoLED | Ahsan Libs:SW_Hotswap_Kailh_1.00u | 99 | C41430893
U3 | W25Q128JVS | Ahsan Libs:SOIC-8_5.23x5.23mm_P1.27mm | 1 | C97521
U4 | RP2040 | Ahsan Libs:RP2040-QFN-56 | 1 | C2040
ESD1 | PRTR5V0U2X | Ahsan Libs:PRTR5V0U2X | 1 | C2827688
LED1,LED2,LED3,LED4,LED5,LED6,LED7,LED8,LED9,LED10,LED11,LED12,LED13,LED14,LED15,LED16,LED17,LED18 | WS2812B | Ahsan Libs:LED_WS2812B_PLCC4_5.0x5.0mm_P3.2mm | 18 | C2761795
RST1 | SW_SPST | Ahsan Libs:K2-1187SQ-A4SW-06 | 1 | C92584
Boot1 | SW_SPST | Ahsan Libs:K2-1187SQ-A4SW-06 | 1 | C92584
C44,C45 | 22pf | Ahsan Libs:JLCPCB_C0402 | 2 | C1555
C33,C43 | 1uf | Ahsan Libs:JLCPCB_C0402 | 2 | C1518208
C5,C6,C7,C8,C9,C11,C12,C13,C14,C15,C16,C18,C19,C20,C21,C22,C23,C24,C25,C26,C34,C35,C36,C37,C38,C39,C40,C41,C42 | 100nf | Ahsan Libs:JLCPCB_C0402 | 29 | C77020
R25,R26 | 22 | Ahsan Libs:JLCPCB_R0402 | 2 | C25092
R21,R22 | 10k | Ahsan Libs:JLCPCB_R0402 | 2 | C25744
R20,R27 | 1k | Ahsan Libs:JLCPCB_R0402 | 2 | C11702
R18,R19 | 5.1K | Ahsan Libs:JLCPCB_R0402 | 2 | C25905
R1,R2,R17 | 470 | Ahsan Libs:JLCPCB_R0402 | 3 | C25117
D1,D2,D3,D4,D5,D6,D7,D8,D9,D10,D11,D12,D13,D14,D15,D16,D17,D18,D19,D20,D21,D22,D23,D24,D25,D26,D27,D28,D29,D30,D31,D32,D33,D34,D35,D36,D37,D38,D39,D40,D41,D42,D43,D44,D45,D46,D47,D48,D49,D50,D51,D52,D53,D54,D55,D56,D57,D58,D59,D60,D61,D62,D63,D64,D66,D67,D68,D69,D71,D72,D73,D74,D75,D76,D77,D78,D79,D80,D81,D82,D83,D84,D85,D86,D87,D88,D89,D90,D91,D92,D93,D94,D95,D96,D97,D98,D99,D100,D101 | 1N4148W | Ahsan Libs:D_SOD-123 | 99 | C81598
Y1 | 12MHz | Ahsan Libs:Crystal_SMD_3225-4Pin_3.2x2.5mm | 1 | C9002
C2,C4,C30,C32 | 100nf | Ahsan Libs:C_0805_2012Metric | 4 | C126469
C1,C3,C10,C17,C27,C29,C31 | 10uf | Ahsan Libs:C_0805_2012Metric | 7 | C440198

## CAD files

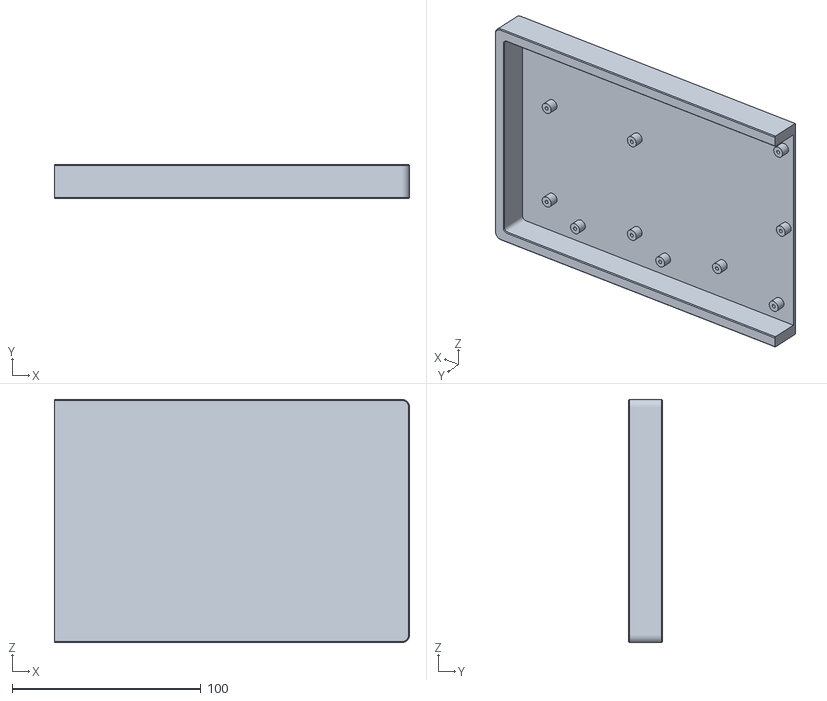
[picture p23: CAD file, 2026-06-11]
Case/96% Case (RobotDoctor)/Main Body/96plate_flat_right.STL
188.0 x 18.0 x 128.8

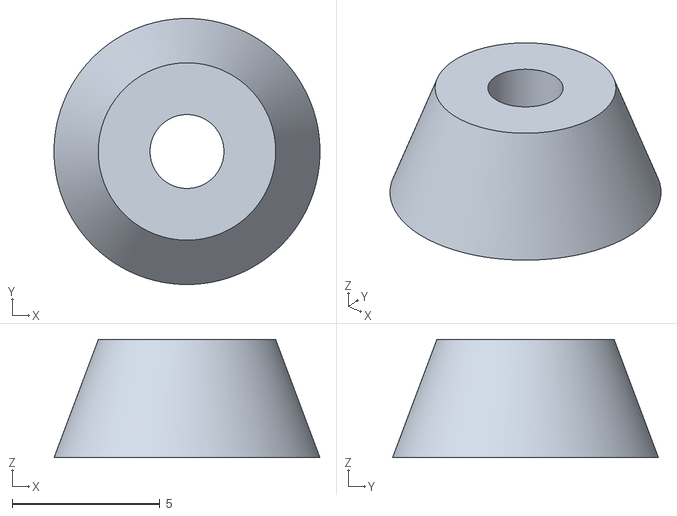
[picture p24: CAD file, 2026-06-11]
Case/Melody96 Case (HughMann)/Hardware/Extra standoff.stl
9.00 x 9.00 x 4.00

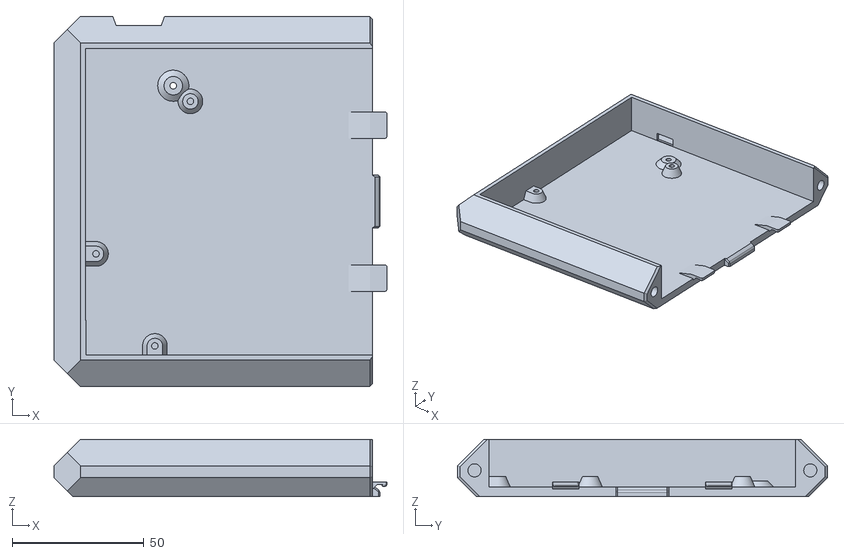
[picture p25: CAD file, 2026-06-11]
Case/Melody96 Case (HughMann)/Main Body/Body L 2mm.stl
126.2 x 140.3 x 21.7

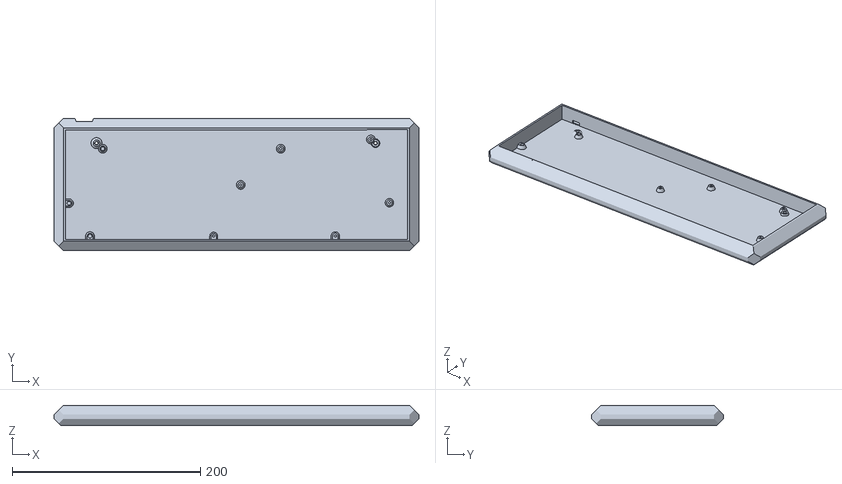
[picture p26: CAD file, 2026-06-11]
Case/Melody96 Case (HughMann)/Remixes/Hope Lost (Sincerity or Rejection) One-Piece File.stl
387.6 x 140.3 x 21.7

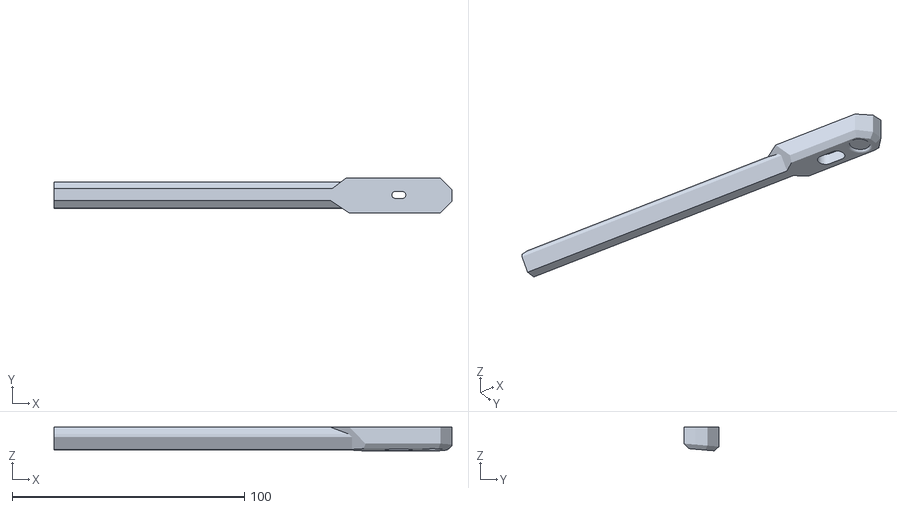
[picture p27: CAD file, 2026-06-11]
Case/Melody96 Case (HughMann)/Risers/5 Degree Riser L.stl
171.2 x 15.0 x 10.2

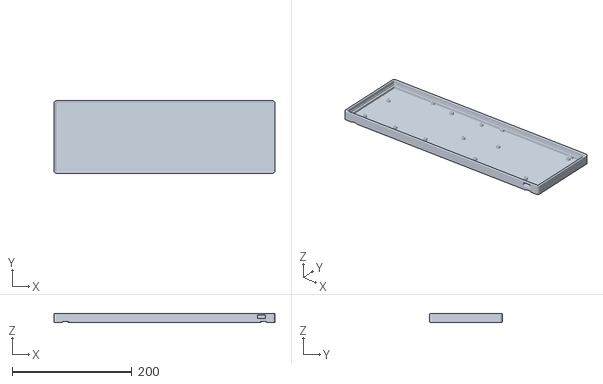
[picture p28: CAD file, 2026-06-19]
Case/SKYWAY Custom (CadQuery)/output/skyway96_case.stl
368.8 x 121.1 x 15.1

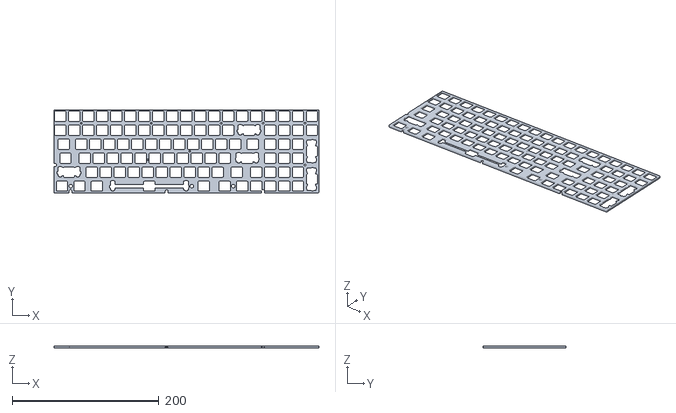
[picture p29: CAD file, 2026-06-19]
Plate (CadQuery)/output/skyway96_plate.stl
361.0 x 113.3 x 3.00

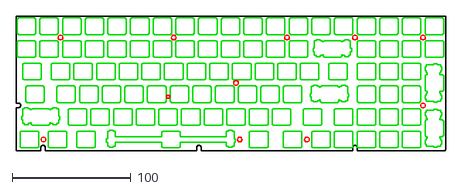
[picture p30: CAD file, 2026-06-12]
Plate/skyway96_plate.dxf
360.9 x 113.3

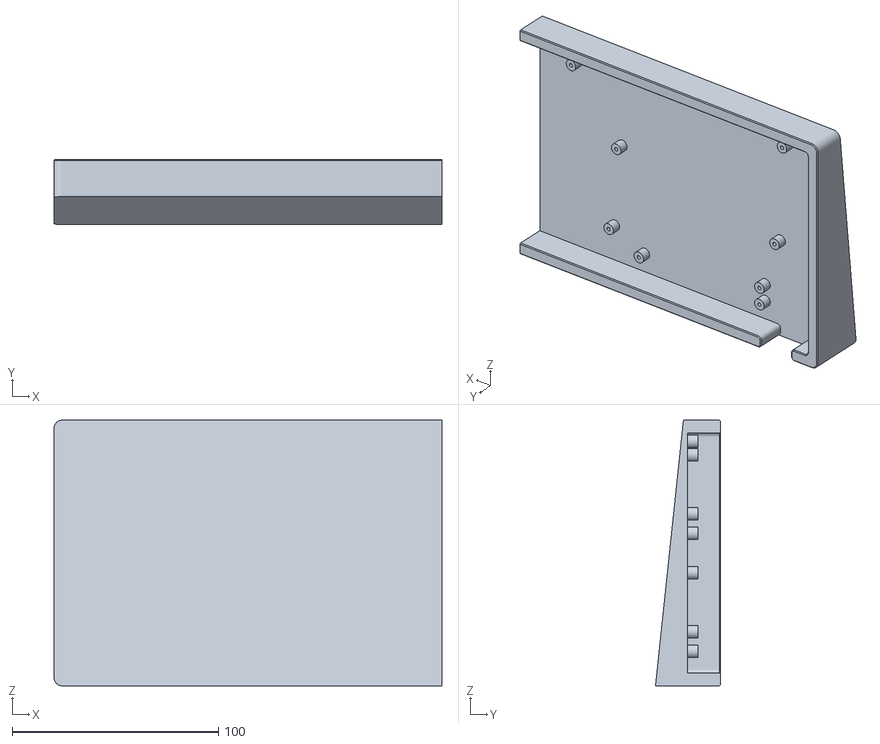
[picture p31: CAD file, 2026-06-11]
Case/96% Case (RobotDoctor)/Main Body/96plate_angle_left.STL
188.0 x 31.5 x 128.8

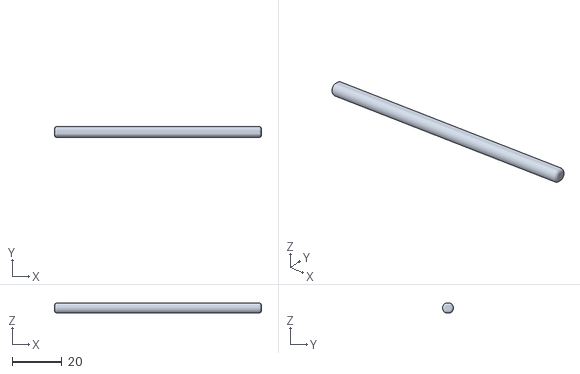
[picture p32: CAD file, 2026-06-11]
Case/Melody96 Case (HughMann)/Hardware/Dowel.stl
83.0 x 4.40 x 4.00

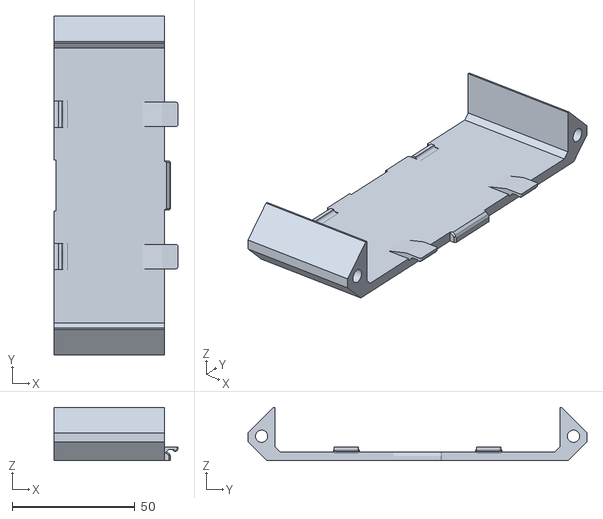
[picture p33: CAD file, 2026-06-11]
Case/Melody96 Case (HughMann)/Main Body/3 Part Stripe.stl
50.5 x 138.3 x 21.7

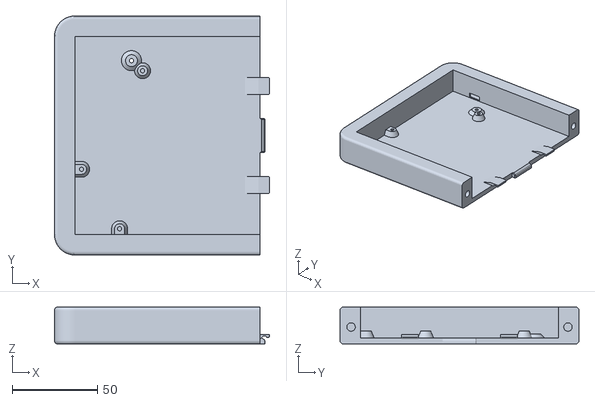
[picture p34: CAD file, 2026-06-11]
Case/Melody96 Case (HughMann)/Remixes/Granular Theory (Stoic Reluctance) Body L M2.stl
126.2 x 140.2 x 21.7

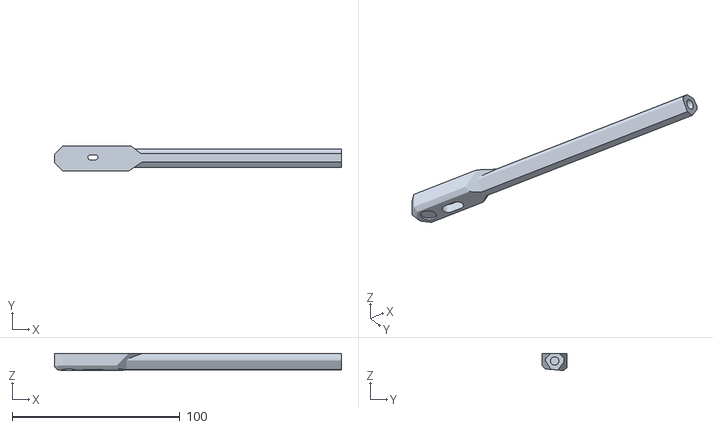
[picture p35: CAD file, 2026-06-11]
Case/Melody96 Case (HughMann)/Risers/5 Degree Riser R.stl
171.2 x 15.0 x 10.2

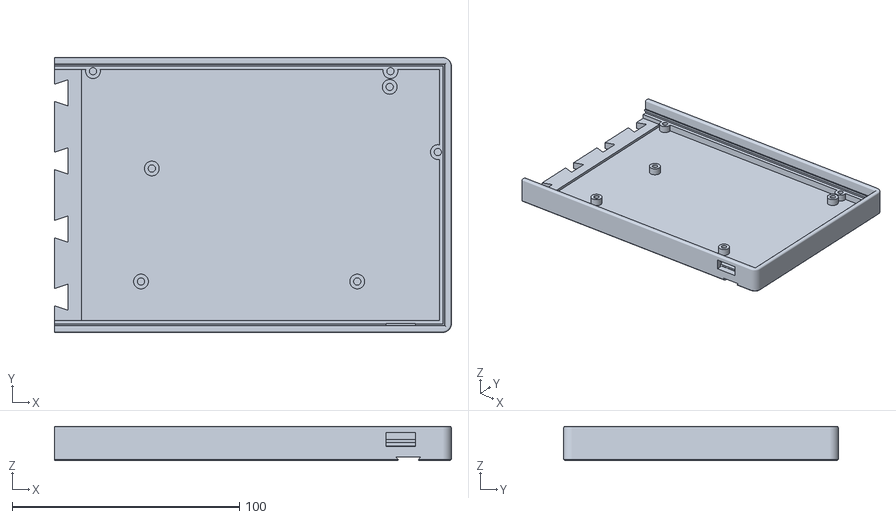
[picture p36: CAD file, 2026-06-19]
Case/SKYWAY Custom (CadQuery)/output/skyway96_right.stl
174.9 x 121.1 x 15.1

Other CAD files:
Plate (CadQuery)/output/skyway96_plate_right.stl
Case/96% Case (RobotDoctor)/Main Body/96plate_angle_right.STL
Case/Melody96 Case (HughMann)/Hardware/Feet.stl
Case/Melody96 Case (HughMann)/Main Body/Body R 2mm.stl
Case/96% Case (RobotDoctor)/Main Body/96plate_flat_left.STL
Case/Melody96 Case (HughMann)/Main Body/Body L.stl
Case/Melody96 Case (HughMann)/Main Body/Body R.stl
Case/Melody96 Case (HughMann)/Main Body/Stripe.stl
Case/Melody96 Case (HughMann)/Remixes/Granular Theory (Stoic Reluctance) Body R M2.stl
Case/Melody96 Case (HughMann)/Remixes/Granular Theory (Stoic Reluctance) Stripe M2.stl
Case/Melody96 Case (HughMann)/Risers/5 Degree Riser Single Piece.stl
Case/RobotDoctor 96% Case (Thingiverse 4401525)/plates/96plate_angle_left.STL
Case/RobotDoctor 96% Case (Thingiverse 4401525)/plates/96plate_angle_right.STL
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

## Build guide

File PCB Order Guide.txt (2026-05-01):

PCB Order Guide:

PCBWAY:
https://www.pcbway.com/helpcenter/Findproducts/How_do_I_place_an_order_.html
https://www.youtube.com/watch?v=HH-DKSiopYk

JLCPCB:
https://support.jlcpcb.com/article/21-how-do-i-place-an-order
https://oshwlab.com/CatherineAlson/How-to-Place-PCB-SMT-Order-on-JLCPCB

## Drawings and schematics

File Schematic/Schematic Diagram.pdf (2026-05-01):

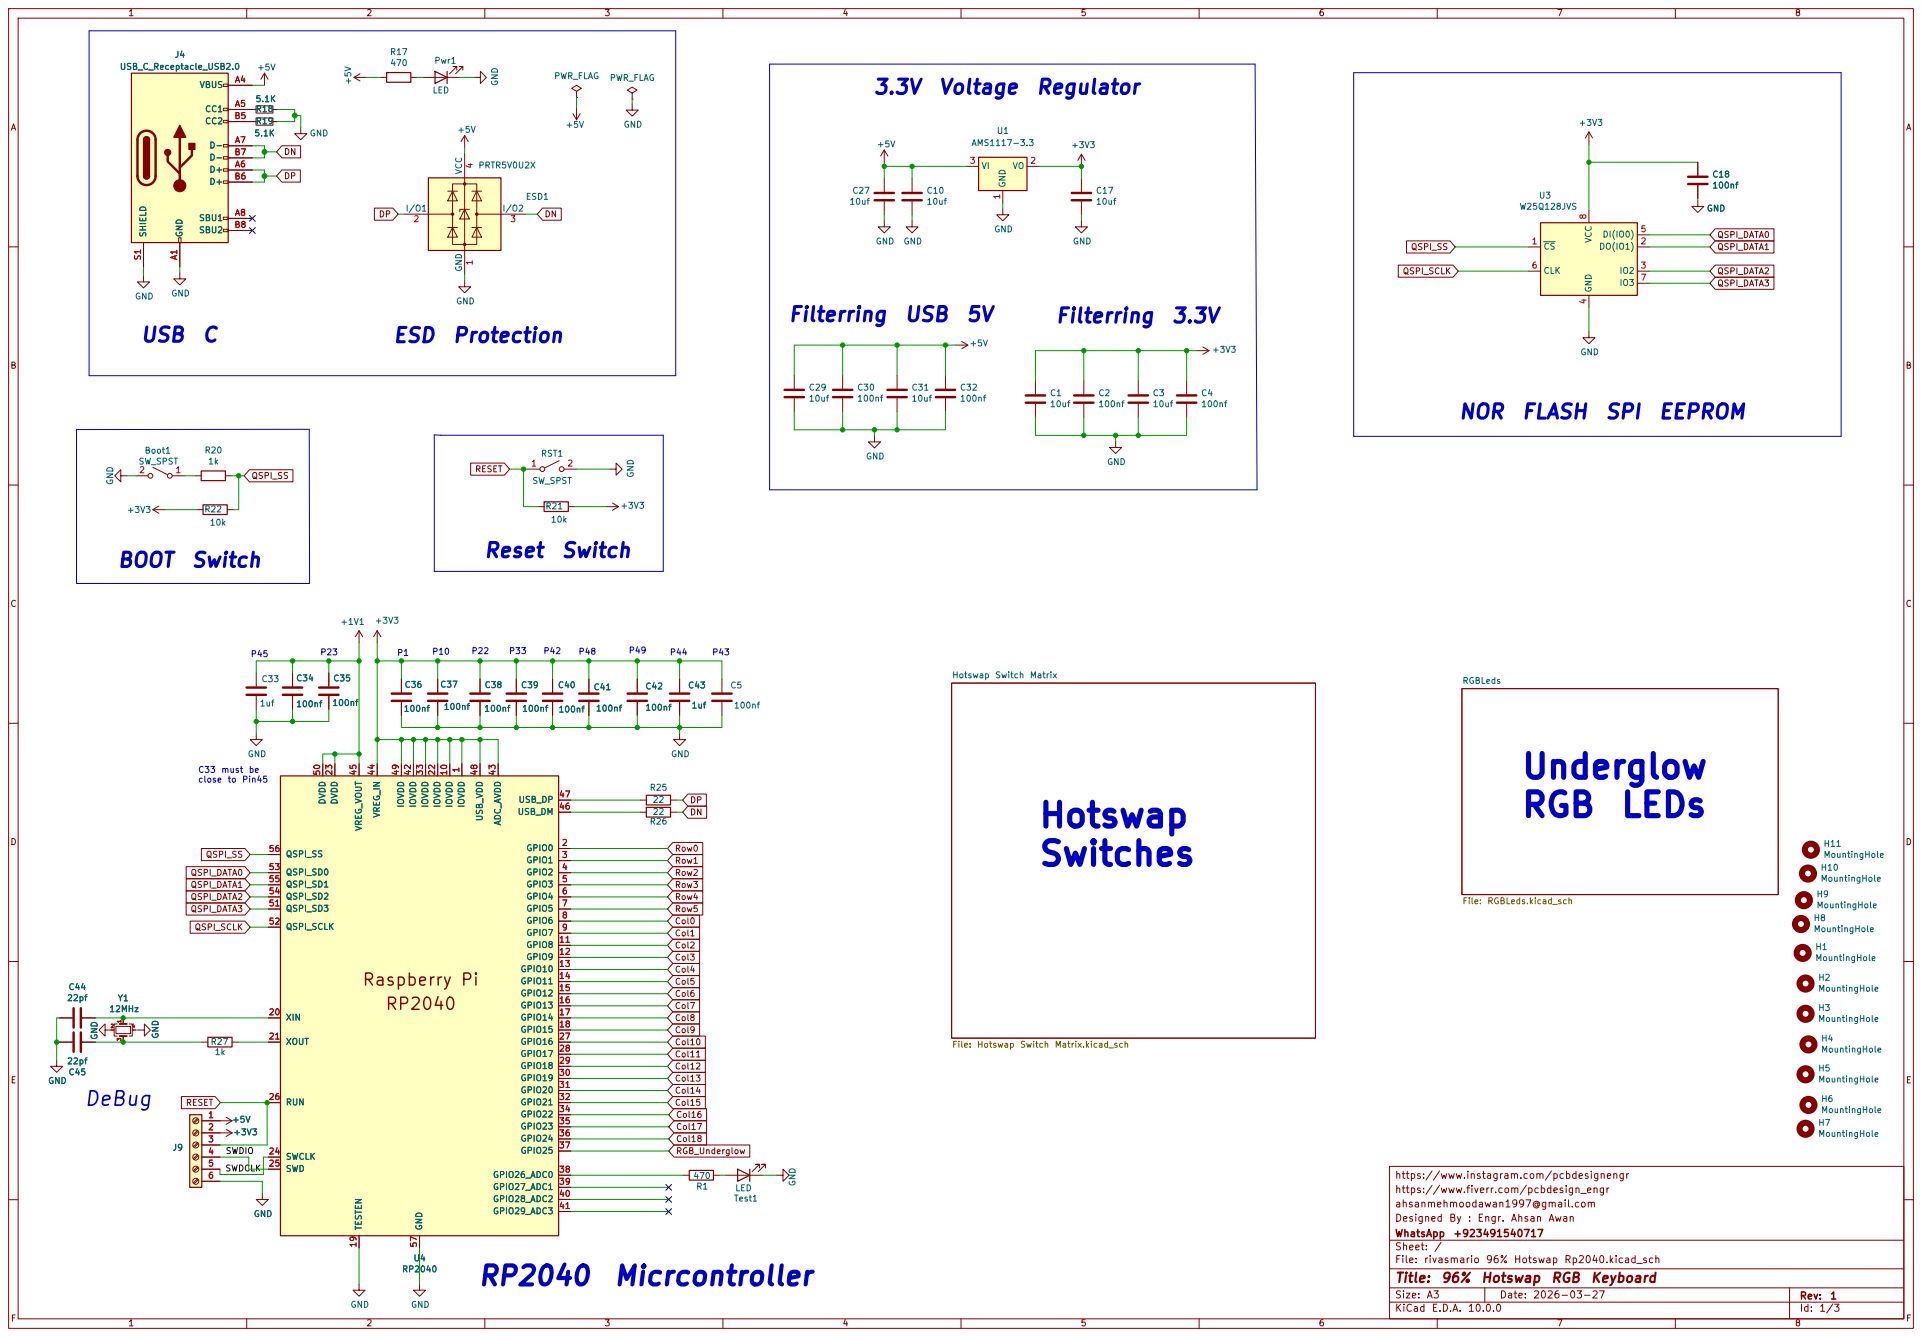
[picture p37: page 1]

NOR FLASH SPI EEPROM

https://www.instagram.com/pcbdesignengr
https://www.fiverr.com/pcbdesign_engr
ahsanmehmoodawan1997@gmail.com
WhatsApp +923491540717 Designed By : Engr. Ahsan Awan

Sheet: /
File: rivasmario 96% Hotswap Rp2040.kicad_sch
Title: 96% Hotswap RGB Keyboard

Size: A3 | Rev: 1 | F Date: 2026-03-27 KiCad E.D.A. 10.0.0

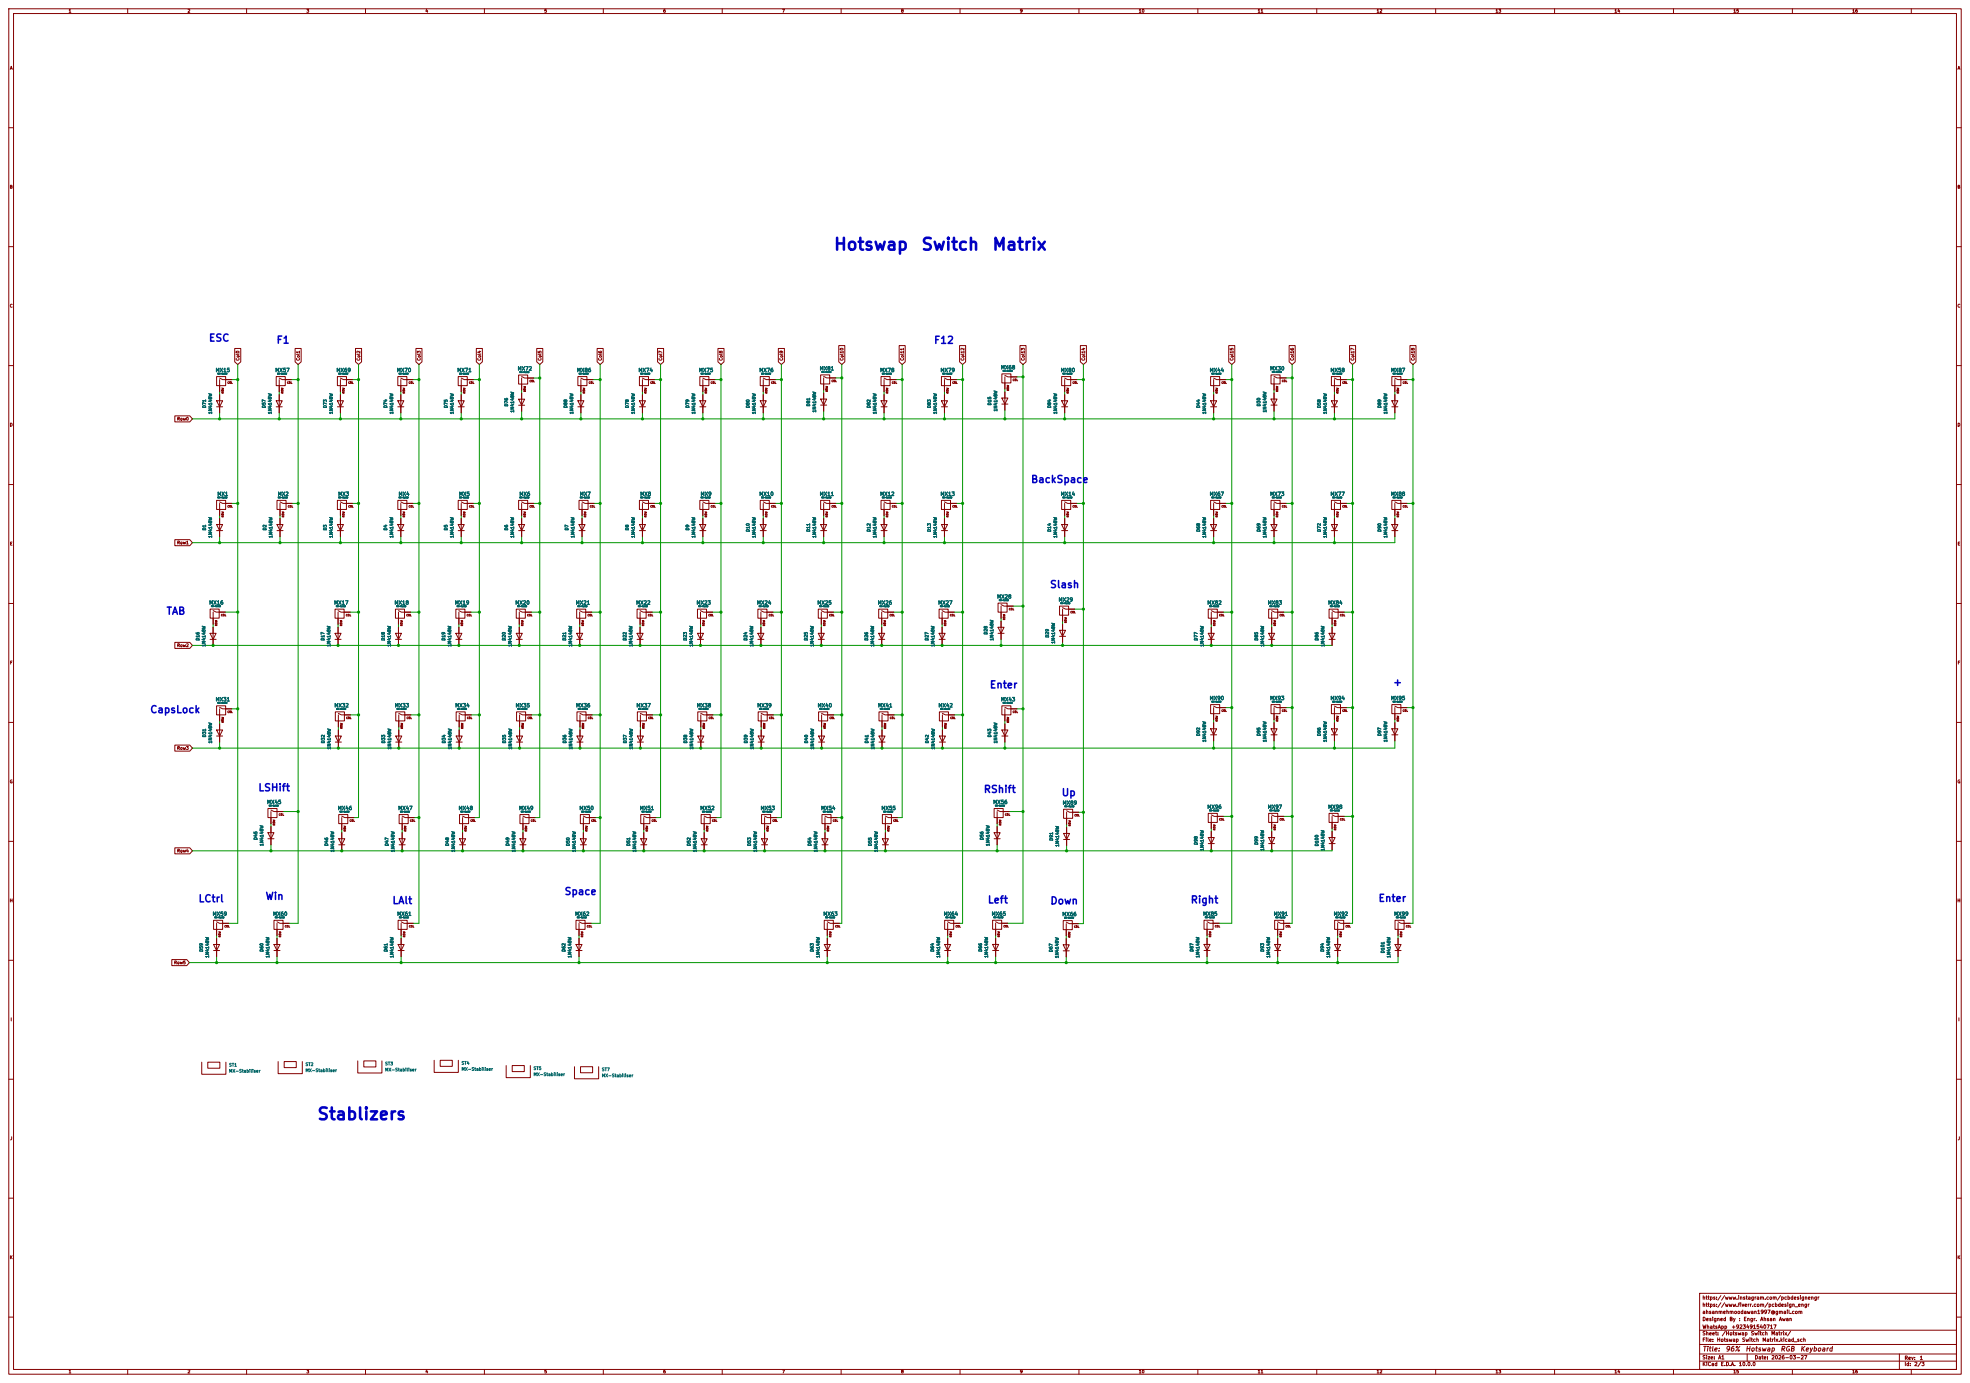
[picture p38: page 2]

Hotswap Switch Matrix
COL MX68 MX-NoLED ROW
COL MX87 MX-NoLED ROW

COL MX55 MX-NoLED ROW

COL MX15 MX-NoLED ROW

COL MX69 MX-NoLED ROW

COL MX3 MX-NoLED ROW

COL MX58 MX-NoLED ROW

COL MX8 MX-NoLED ROW

COL MX81 MX-NoLED ROW

COL MX79 MX-NoLED ROW

MX44 MX-NoLED D44 1N4148W MX67 MX-NoLED D14 1N4148W
MX14 MX-NoLED D84 1N4148W MX80 MX-NoLED

COL MX89 MX-NoLED ROW

COL MX14 MX-NoLED D84 1N4148W ROW

COL MX7 MX-NoLED D88 1N4148W ROW

COL MX73 MX-NoLED ROW

COL MX11 MX-NoLED ROW

COL MX13 MX-NoLED ROW

COL MX25 MX-NoLED D11 1N4148W ROW

COL MX29 MX-NoLED ROW

COL MX28 MX-NoLED ROW

COL MX17 MX-NoLED ROW

COL MX20 MX-NoLED ROW

COL MX82 MX-NoLED ROW

COL MX24 MX-NoLED ROW

COL MX64 MX-NoLED ROW

COL MX91 MX-NoLED D99 1N4148W ROW

COL MX95 MX-NoLED ROW

COL MX35 MX-NoLED ROW

COL MX40 MX-NoLED ROW

COL MX98 MX-NoLED ROW

COL MX66 MX-NoLED ROW

https://www.instagram.com/pcbdesignengr ROW

https://www.fiverr.com/pcbdesign_engr
ahsanmehmoodawan1997@gmail.com
WhatsApp +923491540717 Designed By : Engr. Ahsan Awan

Sheet: /Hotswap Switch Matrix/
File: Hotswap Switch Matrix.kicad_sch

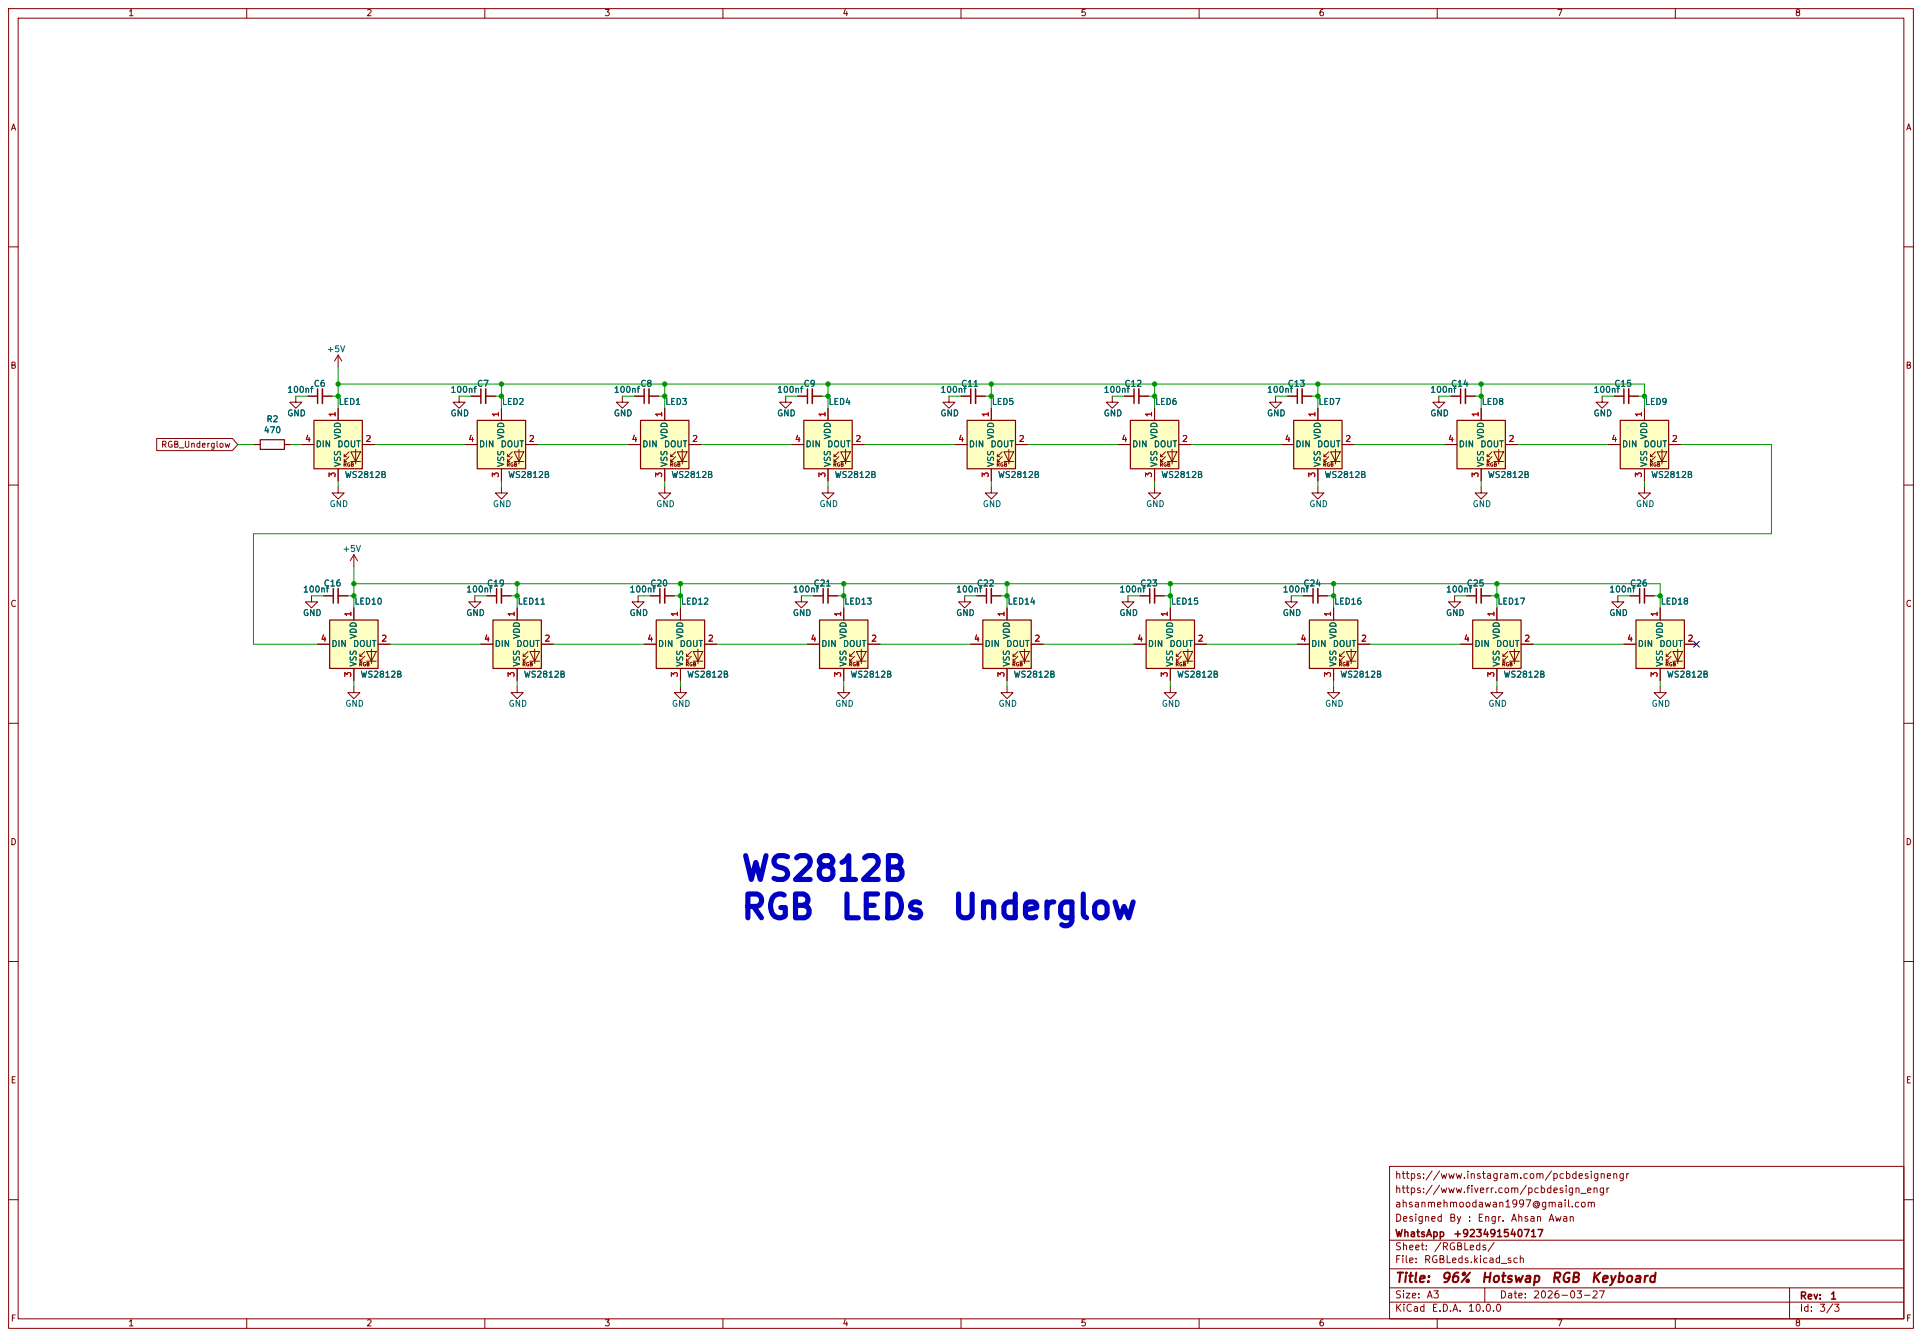
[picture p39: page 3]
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

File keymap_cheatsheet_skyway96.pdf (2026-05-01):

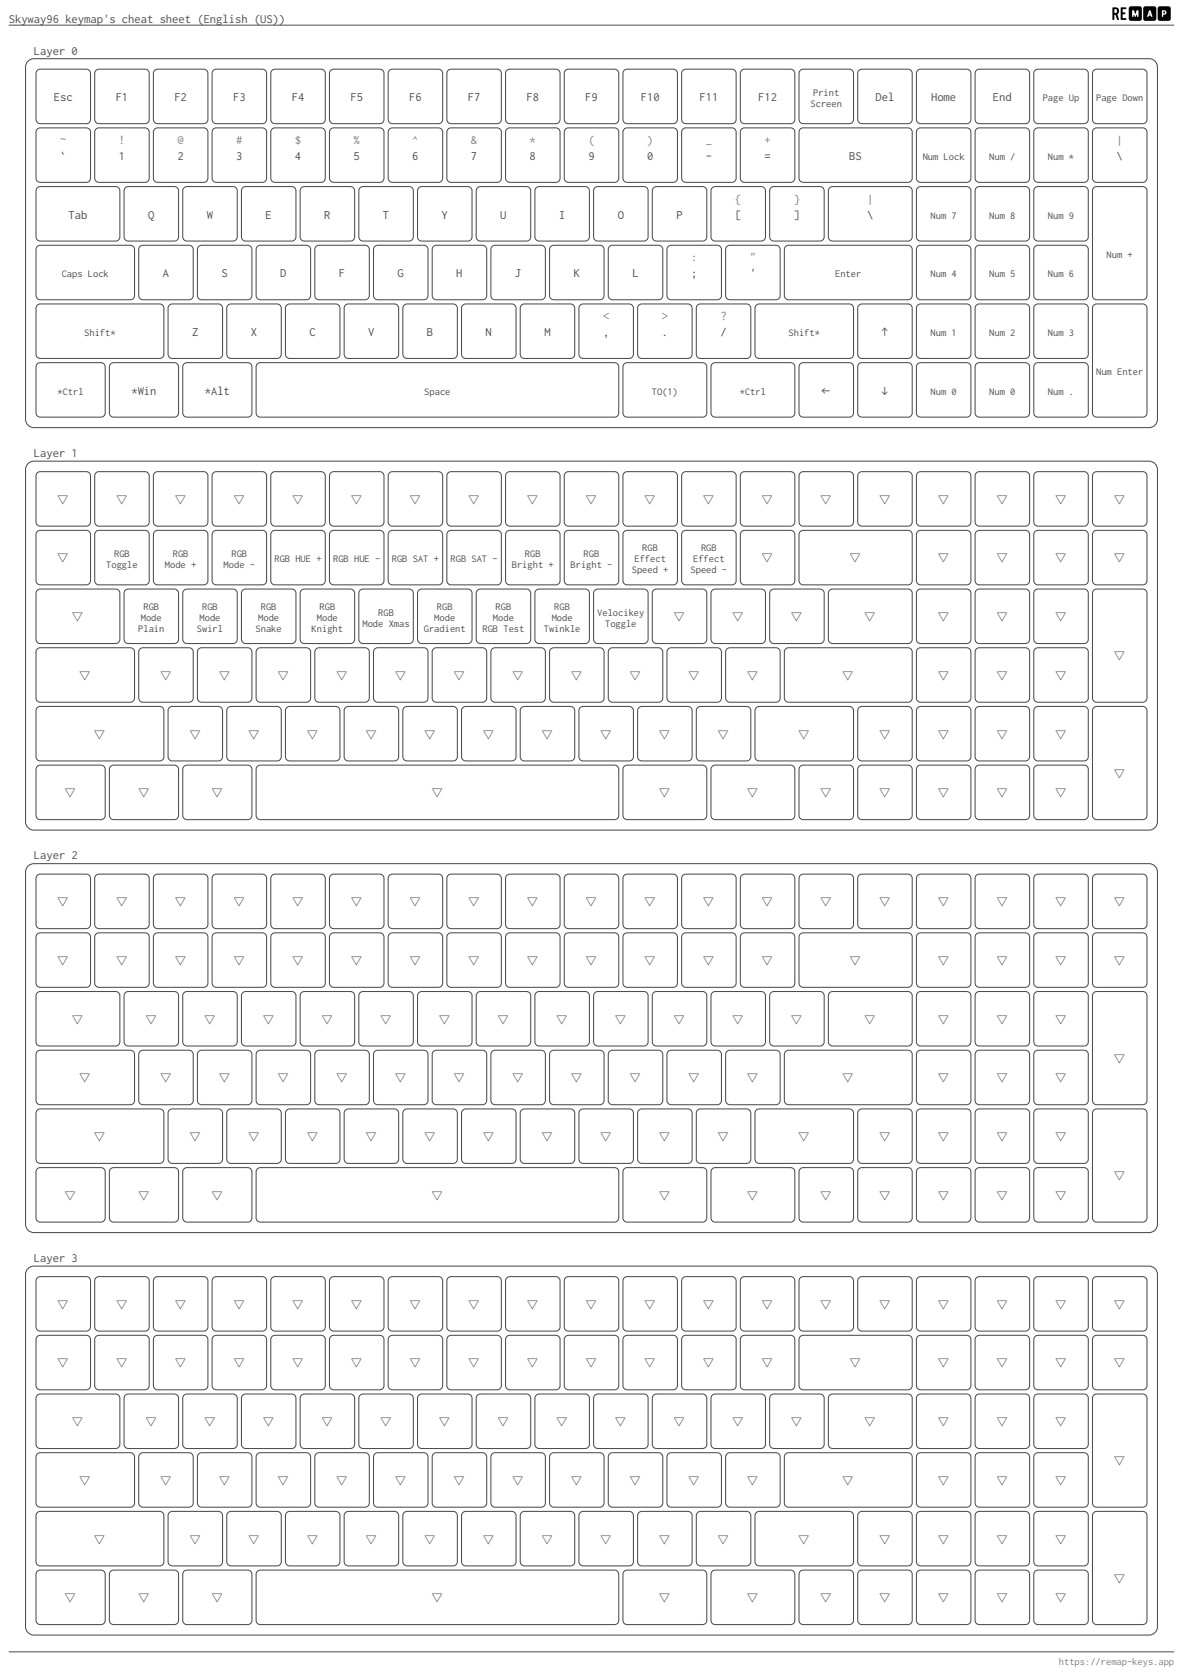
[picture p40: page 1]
Layer 0; Esc; Print; Screen; Del; Home; End; Page Up; Page Down; Num Lock; Num /; Num *; Tab; Num 7; Num 8; Num 9; Num +; Caps Lock; Enter; Num 4; Num 5; Num 6; Shift*; Num 1; Num 2; Num 3; Num Enter; *Ctrl; *Win; *Alt; Space; Num 0; Num .; Layer 1; RGB; Toggle; RGB Mode +; Mode -; RGB HUE + RGB HUE - RGB SAT + RGB SAT -; Bright +; RGB Bright -; RGB Effect Speed +; RGB Effect Speed -; RGB Mode Plain; RGB Mode Swirl; RGB Mode Snake; RGB Mode Knight; RGB Mode Xmas; RGB Mode Gradient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

Skyway96 keymap's cheat sheet (English (US))

https://remap-keys.app

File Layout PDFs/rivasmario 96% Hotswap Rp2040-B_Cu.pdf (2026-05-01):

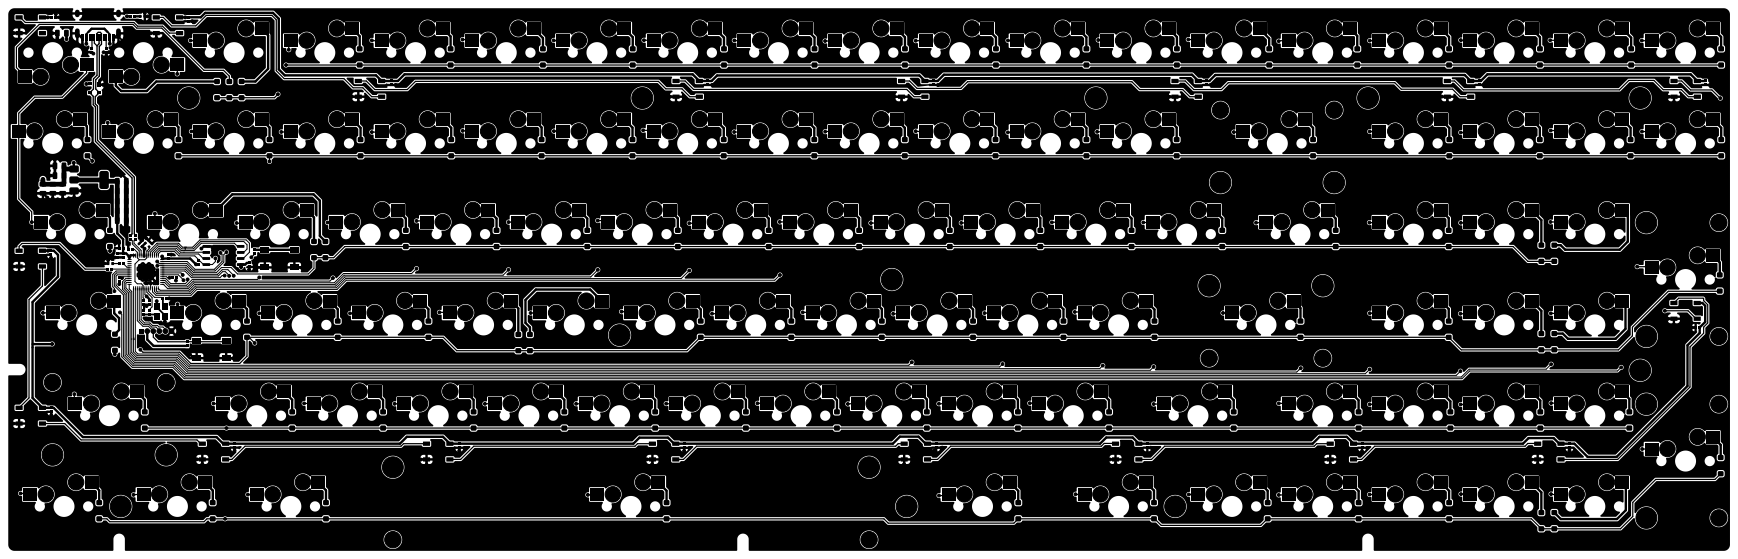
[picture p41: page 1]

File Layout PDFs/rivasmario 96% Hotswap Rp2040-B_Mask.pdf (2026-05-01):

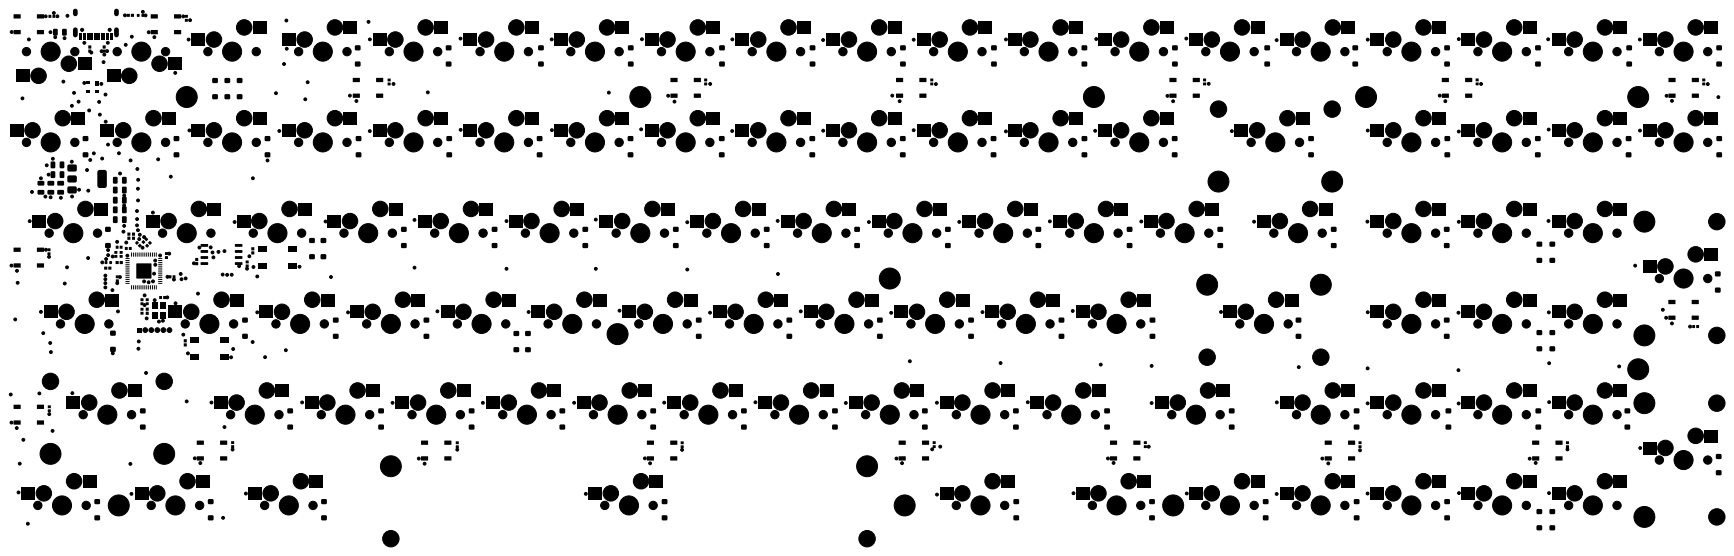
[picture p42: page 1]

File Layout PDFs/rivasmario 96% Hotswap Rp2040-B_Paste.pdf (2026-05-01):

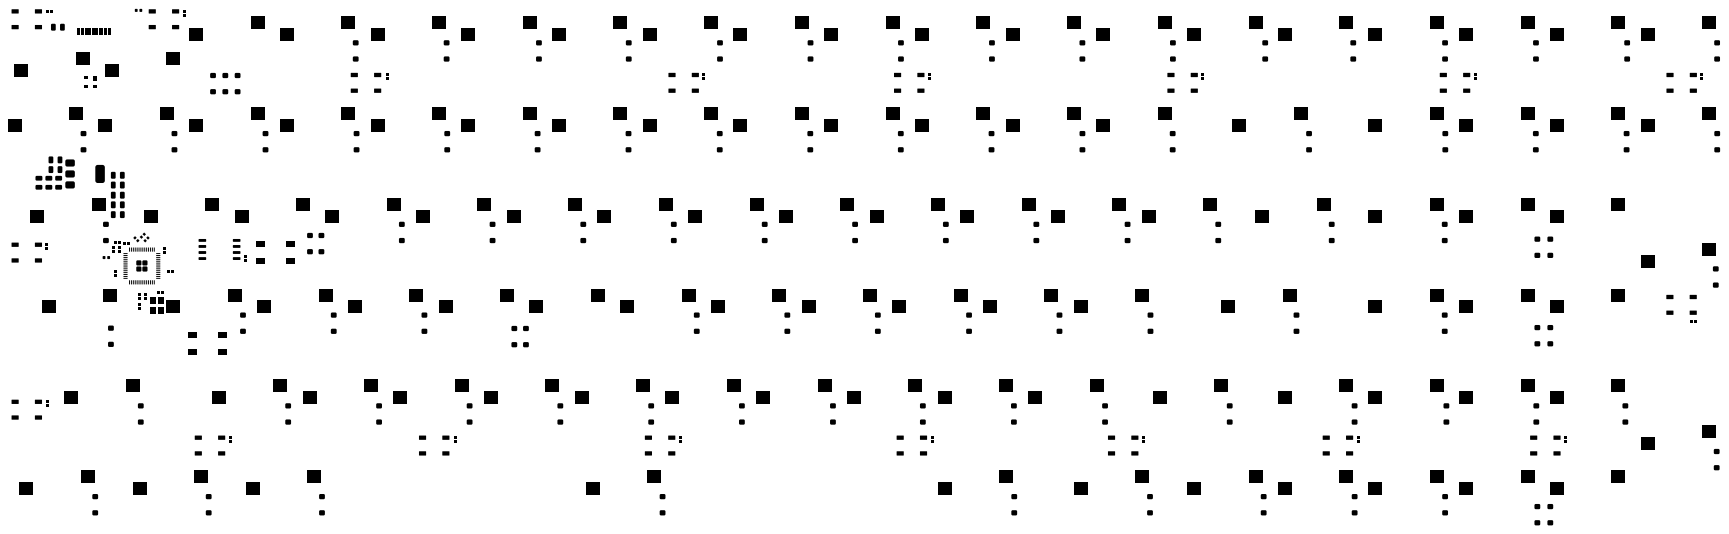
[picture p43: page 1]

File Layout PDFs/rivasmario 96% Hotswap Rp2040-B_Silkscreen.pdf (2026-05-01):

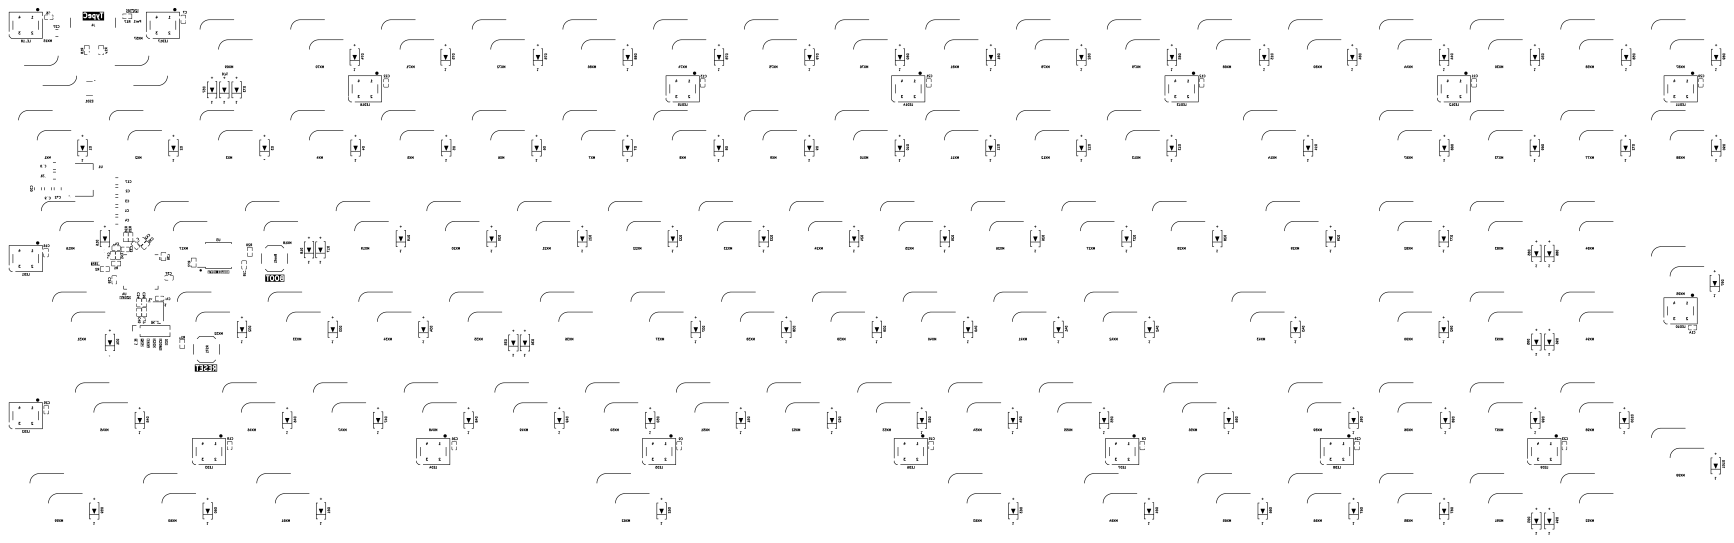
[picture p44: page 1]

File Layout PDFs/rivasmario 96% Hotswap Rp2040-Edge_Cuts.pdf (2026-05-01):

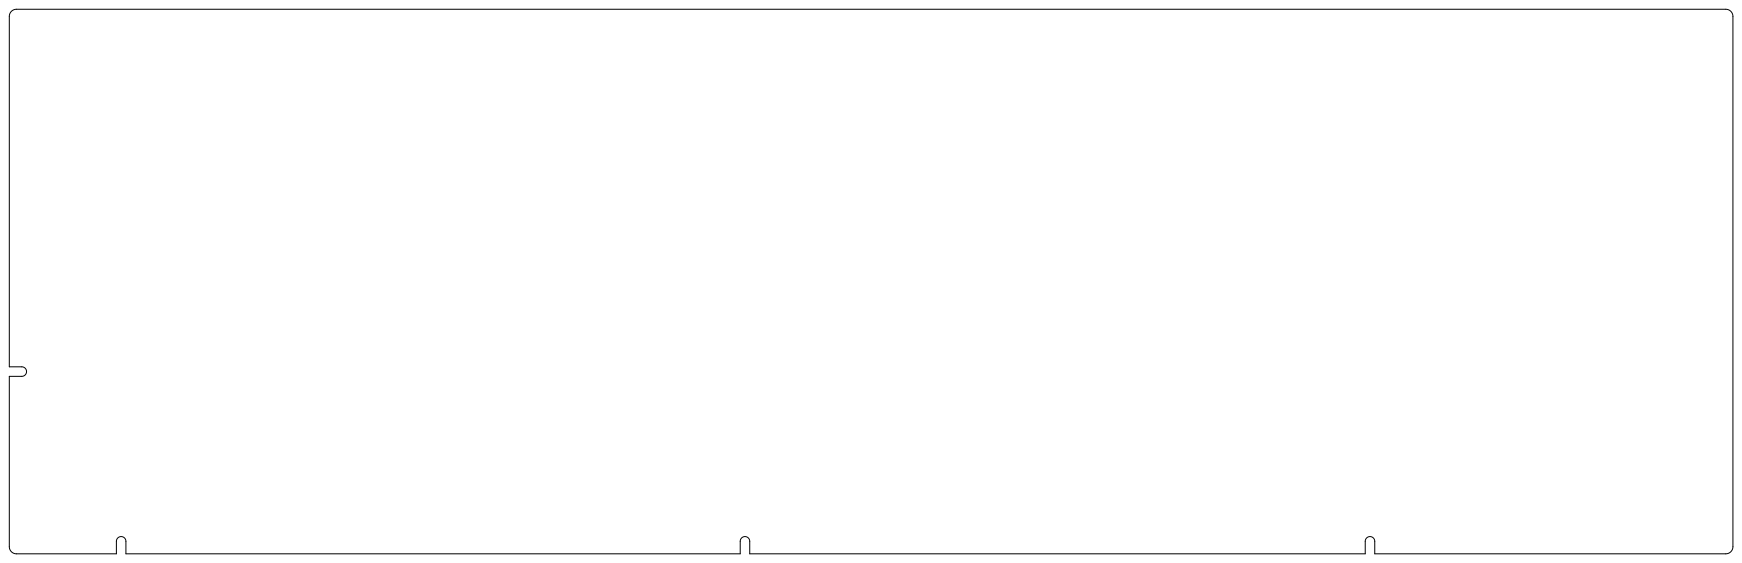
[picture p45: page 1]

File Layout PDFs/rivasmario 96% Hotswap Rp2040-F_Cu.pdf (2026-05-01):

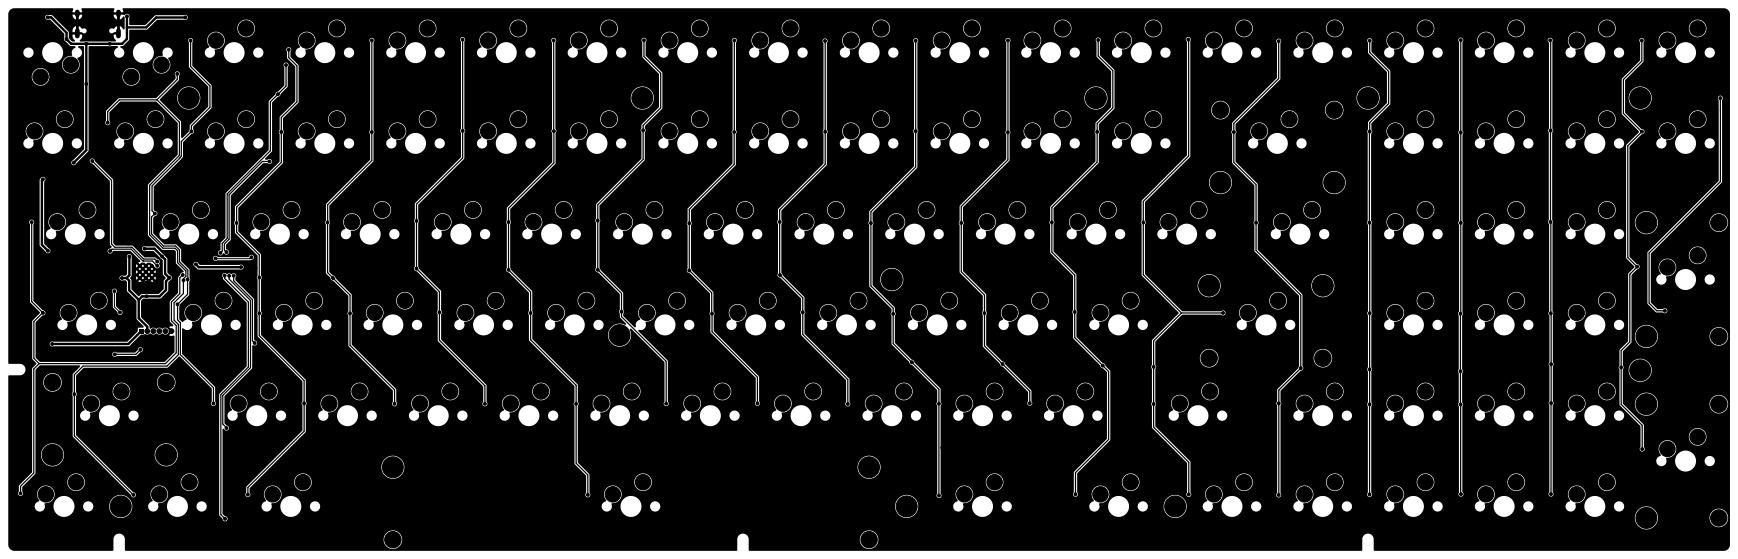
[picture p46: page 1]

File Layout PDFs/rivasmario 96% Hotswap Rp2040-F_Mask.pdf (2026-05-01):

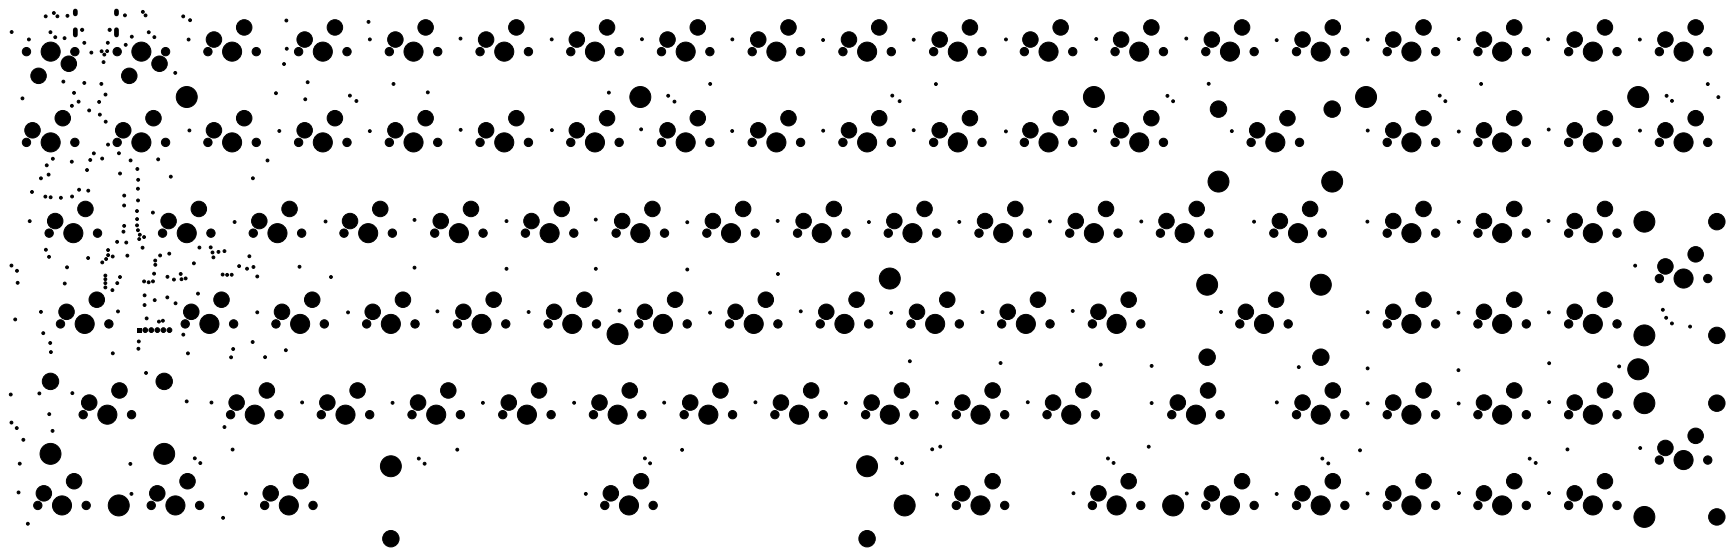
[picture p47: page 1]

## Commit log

2026-04-01 Update print statement from 'Hello' to 'Goodbye'
2026-04-13 chore: rename to Skyway96, update VID/PID to 0x2E8A:0x0096, and modernize firmware
2026-04-14 fix: change VID to 0xFEED for VIA/remap compatibility and rebuild firmware
    RP2040's official VID (0x2E8A) is rejected by VIA and remap-keys.app.
    Switched to 0xFEED:0x0096 (standard QMK custom keyboard VID), rebuilt
    firmware, and added keymap cheatsheet from VIA session.
2026-05-01 feat(devcontainer): mirror dotfiles full setup — Fedora + tailscale + caps + setup.sh
2026-05-26 feat(rgb): bake static white default + rebuild firmware
    Add rgblight default (on, static_light, hue 0 sat 0 val 200) so a
    freshly-flashed board with blank EEPROM boots to white underglow
    instead of QMK fallback red. Rebuild via uf2 against current QMK.
2026-05-26 fix(rgb): make direct mode keys work via custom keycodes
    The Fn-layer RGB_M_* keys did nothing: those legacy keycodes route to
    RGB Matrix (unused; board runs RGBLIGHT underglow). UG_* offers no
    set-specific-mode keycode, so add custom RGBM_* keycodes that call
    rgblight_mode() directly. UG_NEXT/PREV cycling was unaffected.
2026-05-26 chore: clean repo junk
    Remove stale uf2 builds (REBUILT, V70_PATTERNS), old v69 remap JSON,
    and untrack regenerated KiCad caches (fp-info-cache, .history) via
    .gitignore. Untracked remap-experiment JSONs deleted from working tree.
2026-05-26 feat(via): expose RGBM_* modes as named custom keycodes
    Maps USER00-07 to the firmware's RGBM_* handlers so the VIA app shows
    Snake/Knight/etc as assignable buttons. Order matches the keymap enum.
    Reload the definition in VIA to use them.
2026-06-11 Add 3D-printable Melody96 case + improve README
    - Add Case/ with 16 STLs (HughMann Melody96, Thingiverse #3883),
    sorted into Main Body / Risers / Hardware / Remixes
    - Add Case/README.md with part tables, print tips, and a rendered preview
    - Restructure top README: TOC, paired image tables, accurate repo layout,
    cleaner flashing/troubleshooting sections, case preview
    [3 Part Stripe.stl, 5 Degree Riser L.stl, 5 Degree Riser R.stl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]
2026-06-11 Remove misplaced files from repo root
    - Drop 3 scripts hardcoded to the Delta Split 75 project
    (clean_and_update.py, fix_duplicates.py, update_pcb.py)
    - Drop 5 plate-DXF working/handoff notes that belong in the plate repo
    (PLATE_PROJECT, SKYWAY96_RULES, SKYWAY96_DXF_RULES,
    SKYWAY96_INKSCAPE_SCREW_HOLES, SKYWAY96_SCREW_HOLE_ATTEMPTS)
    Still recoverable from git history if needed.
2026-06-11 Add RobotDoctor 96% case (Thingiverse 4401525) + Ø2.4 screw-hole fix
    Alternate 96% case (CC-BY, RobotDoctor). 4 plate STLs (flat/angle ×
    left/right), renders, build steps. PCB-mount bores opened Ø2.0→Ø2.4
    (M2 clearance) via boolean difference — stock Ø2.0 needed hand-drilling.
    Unmodified originals kept in original/plates/. Sign-off render included.
    [96plate_angle_left.STL, 96plate_angle_right.STL, 96plate_flat_left.STL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]
2026-06-12 Add 3D renders of all 4 plates to case README
2026-06-12 Add switch plate (DXF + render) generated by KB_PLATE_VALIDATOR
    100 switch/stab cutouts, 11 M2 screw holes, 361.95x114.30mm. Plate/ holds
    DXF + readme; switch-plate visual added to main README. Generated from
    KLE + KiCad pcb, validated screw/cutout clearance.
    [skyway96_plate.dxf]
2026-06-12 Plate v2 (Ø2.6 screws, +1mm notches, 2-key bottom row) + better Melody96 render
    - Plate: screw holes Ø2.4->Ø2.6 (install wiggle), 4 edge notches grown +1mm,
    RAlt cutout removed (RCtrl+Fn left of arrows). 99 cutouts, 11 screws.
    - Melody96 case-preview re-rendered from STLs with back-face culling
    (replaces faceted/see-through original).
    [skyway96_plate.dxf]
2026-06-12 Plate: bottom row left of arrows = 2 wide keys (1.5u RCtrl+Fn), per PCB
    [skyway96_plate.dxf]
2026-06-12 Plate: screw holes Ø3.2 (per-hole, 1 capped Ø2.65) — bigger install wiggle
    [skyway96_plate.dxf]
2026-06-12 Plate: screw holes Ø3.4 (max wiggle, 0.3mm wall; 1 capped Ø2.85)
    [skyway96_plate.dxf]
2026-06-12 Plate: top-row/intersection screw holes to Ø4.0 (washer); 1 capped Ø2.85
    [skyway96_plate.dxf]
2026-06-12 Consolidate all photos into Photos/, tidy README + repo root
    - Moved 3D Images/ -> Photos/ and pulled loose root images (PCB.png,
    PCB Layout.png, 96% Keyboard.png) into it -> clean repo landing.
    - README: dropped the raw KiCad-editor PCB screenshot, streamlined
    Photos & Renders gallery, fixed all image paths. Updated GEMINI.md.
2026-06-19 Add case designs: 2 mirrored references + custom parametric CadQuery tray
    - Mirror Melody96 (HughMann) and 96% (RobotDoctor) Thingiverse cases with
    READMEs, dimensions, and a Case index.
    - Add SKYWAY Custom: a parametric CadQuery tray fitted to this PCB's real
    outline, USB-C position, and 11 M2 mount holes + 4 edge notches (15 posts).
    Screwless ledge + clamp lip retention, heat-set inserts.
    - Variants: one-piece body, lap... dovetail L/R split (220mm bed), 6 deg
    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
    [96plate_angle_left.STL, 96plate_angle_right.STL, 96plate_flat_left.STL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]
2026-06-19 Add 3D-printable switch plate (CadQuery)
    Stepped 3mm plate generated from the validated laser DXF geometry:
    - top 1.5mm = exact MX clip profile; bottom opened to clear switch housing
    - one-piece + L/R split (seam x=192, jogs around crossed cutouts) for 220mm beds
    - adaptive screw holes (Ø5 where roomy, ~Ø2.5 where switch-crowded), 1mm min wall
    - preflight + 6-view render tooling
    [skyway96_plate.stl, skyway96_plate_left.stl, skyway96_plate_right.stl]
